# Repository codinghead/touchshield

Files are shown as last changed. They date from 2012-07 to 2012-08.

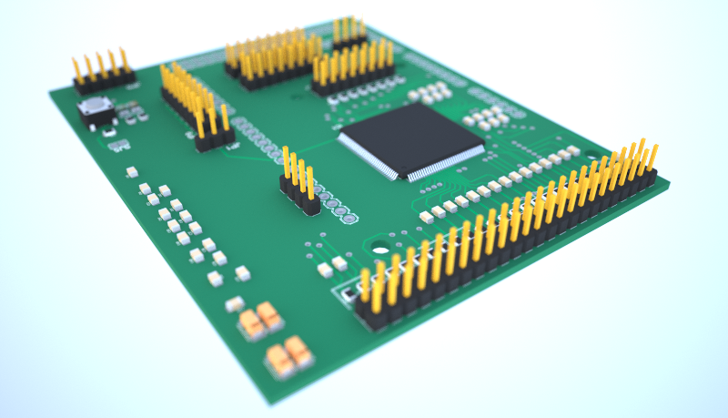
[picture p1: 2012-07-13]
images/QTouchShieldRender.png

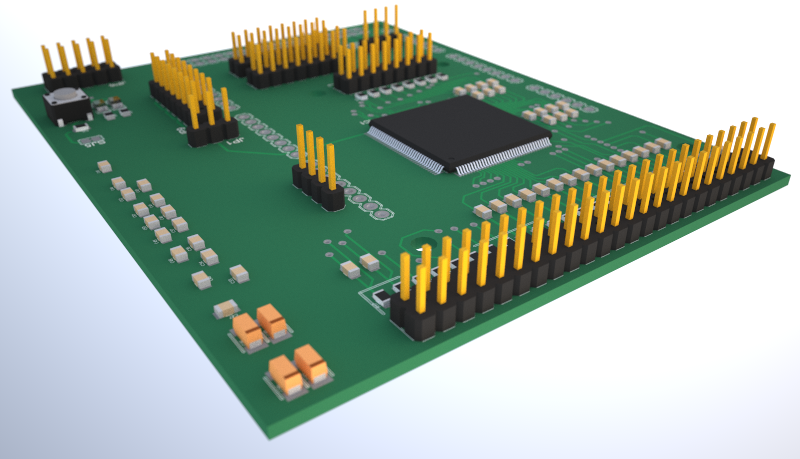
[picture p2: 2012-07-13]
images/QTouchShieldRender3.png

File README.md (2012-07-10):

QTouchShield for Arduino
========================

Introduction to the project
---------------------------

The QTouchShield for Arduino project aims to design a hardware platform for the Arduino MEGA that supports up to 32 configurable capacitive touch inputs.

The inputs can be configured as:

* Buttons
* Sliders
* Wheels
* Proximity sensors

Additionally the project includes the necessary firmware required by the shield's microcontroller to enable this functionality.

Key Capabilties
---------------
* Support up to 32 capacitive touch inputs supporting:
	* up to 8 sliders/wheels
	* up to 32 buttons
	* up to 32 proximity sensors
* Configuration via SPI or UART (RX/TX) interfaces
* Arduino library to simplify integration into sketches

Licensing
---------

The hardware is licensed under the Creative Commons ShareAlike license:

> This work is licensed under the Creative Commons Attribution-ShareAlike 3.0 Unported License.
> To view a copy of this license, visit [http://creativecommons.org/licenses/by-sa/3.0/] (http://creativecommons.org/licenses/by-sa/3.0/) or send
> a letter to:
> Creative Commons, 444 Castro Street, Suite 900, Mountain View, California, 94041, USA.

The software for the project is yet to be developed.

Project Page
------------

For all current information, visit the project page at [codinghead.github.com/touchshield] (http://codinghead.github.com/touchshield/).

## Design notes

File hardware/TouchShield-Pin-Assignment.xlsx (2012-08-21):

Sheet: Pin Assignment
AT32UC3C0512 |  |  | QTouchShield |  |  | Arduino MEGA 2560
LQFP144 Pin | PIN | STK600 | Assignment | Group | Description | Group | PIN | Function | Notes/Comments
1 | PA00 | PA0, TCK | TCK | JTAG | JTAG programming and debug i/f for AT32UC3C
2 | PA01 | PA1, TDI | TDI | JTAG | JTAG programming and debug i/f for AT32UC3C
3 | PA02 | PA2, TDO | TDO | JTAG | JTAG programming and debug i/f for AT32UC3C
4 | PA03 | PA3, TMS | TMS | JTAG | JTAG programming and debug i/f for AT32UC3C
5 | VDDIO1 | --- | 5.0V | SUPPLY | Power supply connection | POWER | 5V | 5V
6 | GNDIO1 | --- | 0.0V | SUPPLY | Power supply connection | POWER | GND | GND
7 | PB04 | PE4 | SNS04 | QT-SENSE | QTouch sense connection |  |  |  | Connect via X.XnF capacitor to SNSK04
8 | PB05 | PE5 | SNS05 | QT-SENSE | QTouch sense connection |  |  |  | Connect via X.XnF capacitor to SNSK05
9 | PB06 | PE6 | SNS06 | QT-SENSE | QTouch sense connection |  |  |  | Connect via X.XnF capacitor to SNSK06
10 | PB07 | PE7 | SNS07 | QT-SENSE | QTouch sense connection |  |  |  | Connect via X.XnF capacitor to SNSK07
11 | PB08 | PF0 | SNS08 | QT-SENSE | QTouch sense connection |  |  |  | Connect via X.XnF capacitor to SNSK08
12 | PB09 | PF1 | SNS09 | QT-SENSE | QTouch sense connection |  |  |  | Connect via X.XnF capacitor to SNSK09
13 | PB10 | PF2 | SNS10 | QT-SENSE | QTouch sense connection |  |  |  | Connect via X.XnF capacitor to SNSK10
14 | PB11 | PF3 | SNS11 | QT-SENSE | QTouch sense connection |  |  |  | Connect via X.XnF capacitor to SNSK11
15 | PB12 | PF4 | SNS12 | QT-SENSE | QTouch sense connection |  |  |  | Connect via X.XnF capacitor to SNSK12
16 | PB13 | PF5 | SNS13 | QT-SENSE | QTouch sense connection |  |  |  | Connect via X.XnF capacitor to SNSK13
17 | PB14 | PF6 | SNS14 | QT-SENSE | QTouch sense connection |  |  |  | Connect via X.XnF capacitor to SNSK14
18 | PB15 | PF7 | SNS15 | QT-SENSE | QTouch sense connection |  |  |  | Connect via X.XnF capacitor to SNSK15
19 | PB16 | PG0 | SNS16 | QT-SENSE | QTouch sense connection |  |  |  | Connect via X.XnF capacitor to SNSK16
20 | PB17 | PG1 | SNS17 | QT-SENSE | QTouch sense connection |  |  |  | Connect via X.XnF capacitor to SNSK17
21 | PA04 | PA4 | DETECT | QT-DETECT-GENERAL | At least one sensor is in detect - visual output |  |  |  | LED output to blink when a touch is detected on any of the inputs
22 | PA05 | PA5 | DATA_TRANSFER | SHIELD-DATA-TRANSFER | Data is being transferred on data link - visual output |  |  |  | LED output to blink when data is being shared with the Arduino
23 | PA06 | PA6 | DETECT-SENSOR00 | SHIELD-DETECT-OUTPUT | Digital output for detection on sensor 00
24 | PA07 | PA7 | DETECT-SENSOR01 | SHIELD-DETECT-OUTPUT | Digital output for detection on sensor 01
25 | PA08 | PB0 | DETECT-SENSOR02 | SHIELD-DETECT-OUTPUT | Digital output for detection on sensor 02
26 | PA09 | PB1 | DETECT-SENSOR03 | SHIELD-DETECT-OUTPUT | Digital output for detection on sensor 03
27 | PA10 | PB2 | DETECT-SENSOR04 | SHIELD-DETECT-OUTPUT | Digital output for detection on sensor 04
28 | PA11 | PB3, AREF1 | DETECT-SENSOR05 | SHIELD-DETECT-OUTPUT | Digital output for detection on sensor 05
29 | PA12 | PB4 | DETECT-SENSOR06 | SHIELD-DETECT-OUTPUT | Digital output for detection on sensor 06
30 | PA13 | PB5 | DETECT-SENSOR07 | SHIELD-DETECT-OUTPUT | Digital output for detection on sensor 07
31 | PA14 | PB6 | DETECT-SENSOR08 | SHIELD-DETECT-OUTPUT | Digital output for detection on sensor 08
32 | PA15 | PB7 | DETECT-SENSOR09 | SHIELD-DETECT-OUTPUT | Digital output for detection on sensor 09
33 | PA16 | PC0, AREF0 | DETECT-SENSOR10 | SHIELD-DETECT-OUTPUT | Digital output for detection on sensor 10
34 | ADCVREFP | --- | NC | NO_FUNCTION |  |  |  |  | Connect to ADCREFN via parallel capacitors of 33nF and 100nF
35 | ADCVREFN | --- | NC | NO_FUNCTION |  |  |  |  | Connect to ADCREFP via parallel capacitors of 33nF and 100nF
36 | PA19 | PC3 | DETECT-SENSOR11 | SHIELD-DETECT-OUTPUT | Digital output for detection on sensor 11
37 | GNDANA | --- | 0.0V | SUPPLY | Power supply connection | POWER | GND | GND | Connect via decoupling capacitors to UC3C to VDDANA
38 | VDDANA | VTG | 5.0V | SUPPLY | Power supply connection | POWER | 5V | 5V | Connect via inductor to 5V on Arduino
39 | PA20 | PC4 | DETECT-SENSOR12 | SHIELD-DETECT-OUTPUT | Digital output for detection on sensor 12
40 | PA21 | PC5 | DETECT-SENSOR13 | SHIELD-DETECT-OUTPUT | Digital output for detection on sensor 13
41 | PA22 | PC6 | DETECT-SENSOR14 | SHIELD-DETECT-OUTPUT | Digital output for detection on sensor 14
42 | PA23 | PC7 | DETECT-SENSOR15 | SHIELD-DETECT-OUTPUT | Digital output for detection on sensor 15
43 | PA24 | PD0 | DETECT-SENSOR16 | SHIELD-DETECT-OUTPUT | Digital output for detection on sensor 16
44 | PA25 | PD1 | DETECT-SENSOR17 | SHIELD-DETECT-OUTPUT | Digital output for detection on sensor 17
45 | PA26 | PD2 | DETECT-SENSOR18 | SHIELD-DETECT-OUTPUT | Digital output for detection on sensor 18
46 | PA27 | PD3 | DETECT-SENSOR19 | SHIELD-DETECT-OUTPUT | Digital output for detection on sensor 19
47 | PA28 | PD4 | DETECT-SENSOR20 | SHIELD-DETECT-OUTPUT | Digital output for detection on sensor 20
48 | PA29 | PD5 | DETECT-SENSOR21 | SHIELD-DETECT-OUTPUT | Digital output for detection on sensor 21
49 | VBUS | VBUST | 0.0V | SUPPLY |  | POWER | GND | GND | ??? Connect this unused pin to ground ???
50 | DM | DN | NC | NO_FUNCTION |  |  |  |  | ??? Perhaps use for USB firmware upgrade ???
51 | DP | DP | NC | NO_FUNCTION |  |  |  |  | ??? Perhaps use for USB firmware upgrade ???
52 | GNDPLL | --- | 0.0V | SUPPLY |  | POWER | GND | GND
53 | VDDIN_5 | --- | 5.0V | SUPPLY |  | POWER | 5V | 5V
54 | VDDIN_33 | --- | Regulator Decoupling | SUPPLY | Power supply decoupling | POWER | GND | GND | Connect via decoupling capacitors to GND
55 | VDDCORE | 0 | Regulator Decoupling | SUPPLY | Power supply decoupling | POWER | GND | GND | Connect via decoupling capacitors to GND
56 | GNDCORE | --- | 0.0V | SUPPLY |  | POWER | GND | GND
57 | PB18 | PG2 | SNS18 | QT-SENSE | QTouch sense connection |  |  |  | Connect via X.XnF capacitor to SNSK18
58 | PB19 | PG3 | SNS19 | QT-SENSE | QTouch sense connection |  |  |  | Connect via X.XnF capacitor to SNSK19
59 | PB20 | PG4 | SNS20 | QT-SENSE | QTouch sense connection |  |  |  | Connect via X.XnF capacitor to SNSK20
60 | PB21 | PG5 | SNS21 | QT-SENSE | QTouch sense connection |  |  |  | Connect via X.XnF capacitor to SNSK21
61 | PB22 | PG6 | SNS22 | QT-SENSE | QTouch sense connection |  |  |  | Connect via X.XnF capacitor to SNSK22
62 | PB23 | PG7 | SNS23 | QT-SENSE | QTouch sense connection |  |  |  | Connect via X.XnF capacitor to SNSK23
63 | PB24 | PH0 | SNS24 | QT-SENSE | QTouch sense connection |  |  |  | Connect via X.XnF capacitor to SNSK24
64 | PB25 | PH1 | SNS25 | QT-SENSE | QTouch sense connection |  |  |  | Connect via X.XnF capacitor to SNSK25
65 | PB26 | PH2 | SNS26 | QT-SENSE | QTouch sense connection |  |  |  | Connect via X.XnF capacitor to SNSK26
66 | PB27 | PH3 | SNS27 | QT-SENSE | QTouch sense connection |  |  |  | Connect via X.XnF capacitor to SNSK27
67 | PB28 | PH4 | SNS28 | QT-SENSE | QTouch sense connection |  |  |  | Connect via X.XnF capacitor to SNSK28
68 | PB29 | PH5 | SNS29 | QT-SENSE | QTouch sense connection |  |  |  | Connect via X.XnF capacitor to SNSK29
69 | PB30 | PH6, XTAL1 | SNS30 | QT-SENSE | QTouch sense connection |  |  |  | Connect via X.XnF capacitor to SNSK30
70 | PB31 | PH7, XTAL2 | SNS31 | QT-SENSE | QTouch sense connection |  |  |  | Connect via X.XnF capacitor to SNSK31
71 | PC00 | PJ0 | SNSK00 | QT-SENSE-KEY | QTouch key connection |  |  |  | Connect to X.XkOhn resistor -> header with local header pin for GND of sensor wiring
72 | PC01 | PJ1, UVCON | SNSK01 | QT-SENSE-KEY | QTouch key connection |  |  |  | Connect to X.XkOhn resistor -> header with local header pin for GND of sensor wiring
73 | PC02 | PJ2 | SNSK02 | QT-SENSE-KEY | QTouch key connection |  |  |  | Connect to X.XkOhn resistor -> header with local header pin for GND of sensor wiring
74 | PC03 | PJ3 | SNSK03 | QT-SENSE-KEY | QTouch key connection |  |  |  | Connect to X.XkOhn resistor -> header with local header pin for GND of sensor wiring
75 | VDDIO2 | --- | 5.0V | SUPPLY | Supply | POWER | 5V | 5V
76 | GNDIO2 | --- | 0.0V | SUPPLY | Supply | POWER | GND | GND
77 | PC04 | PJ4 | SNSK04 | QT-SENSE-KEY | QTouch key connection |  |  |  | Connect to X.XkOhn resistor -> header with local header pin for GND of sensor wiring
78 | PC05 | PJ5 | SNSK05 | QT-SENSE-KEY | QTouch key connection |  |  |  | Connect to X.XkOhn resistor -> header with local header pin for GND of sensor wiring
79 | PC06 | PJ6 | SNSK06 | QT-SENSE-KEY | QTouch key connection |  |  |  | Connect to X.XkOhn resistor -> header with local header pin for GND of sensor wiring
80 | PC07 | PJ7 | SNSK07 | QT-SENSE-KEY | QTouch key connection |  |  |  | Connect to X.XkOhn resistor -> header with local header pin for GND of sensor wiring
81 | PC08 | PK0 | SNSK08 | QT-SENSE-KEY | QTouch key connection |  |  |  | Connect to X.XkOhn resistor -> header with local header pin for GND of sensor wiring
82 | PC09 | PK1 | SNSK09 | QT-SENSE-KEY | QTouch key connection |  |  |  | Connect to X.XkOhn resistor -> header with local header pin for GND of sensor wiring
83 | PC10 | PK2 | SNSK10 | QT-SENSE-KEY | QTouch key connection |  |  |  | Connect to X.XkOhn resistor -> header with local header pin for GND of sensor wiring
84 | PC11 | PK3 | SNSK11 | QT-SENSE-KEY | QTouch key connection |  |  |  | Connect to X.XkOhn resistor -> header with local header pin for GND of sensor wiring
85 | PC12 | PK4 | SNSK12 | QT-SENSE-KEY | QTouch key connection |  |  |  | Connect to X.XkOhn resistor -> header with local header pin for GND of sensor wiring
86 | PC13 | PK5 | SNSK13 | QT-SENSE-KEY | QTouch key connection |  |  |  | Connect to X.XkOhn resistor -> header with local header pin for GND of sensor wiring
87 | PC14 | PK6 | SNSK14 | QT-SENSE-KEY | QTouch key connection |  |  |  | Connect to X.XkOhn resistor -> header with local header pin for GND of sensor wiring
88 | PC15 | PK7 | SNSK15 | QT-SENSE-KEY | QTouch key connection |  |  |  | Connect to X.XkOhn resistor -> header with local header pin for GND of sensor wiring
89 | PC16 | PL0 | SNSK16 | QT-SENSE-KEY | QTouch key connection |  |  |  | Connect to X.XkOhn resistor -> header with local header pin for GND of sensor wiring
90 | PC17 | PL1 | SNSK17 | QT-SENSE-KEY | QTouch key connection |  |  |  | Connect to X.XkOhn resistor -> header with local header pin for GND of sensor wiring
91 | PC18 | PL2 | SNSK18 | QT-SENSE-KEY | QTouch key connection |  |  |  | Connect to X.XkOhn resistor -> header with local header pin for GND of sensor wiring
92 | PC19 | PL3 | SNSK19 | QT-SENSE-KEY | QTouch key connection |  |  |  | Connect to X.XkOhn resistor -> header with local header pin for GND of sensor wiring
93 | PC20 | PL4 | SNSK20 | QT-SENSE-KEY | QTouch key connection |  |  |  | Connect to X.XkOhn resistor -> header with local header pin for GND of sensor wiring
94 | PC21 | PL5 | SNSK21 | QT-SENSE-KEY | QTouch key connection |  |  |  | Connect to X.XkOhn resistor -> header with local header pin for GND of sensor wiring
95 | PC22 | PL6 | SNSK22 | QT-SENSE-KEY | QTouch key connection |  |  |  | Connect to X.XkOhn resistor -> header with local header pin for GND of sensor wiring
96 | PC23 | PL7 | SNSK23 | QT-SENSE-KEY | QTouch key connection |  |  |  | Connect to X.XkOhn resistor -> header with local header pin for GND of sensor wiring
97 | PC24 | PM0 | SNSK24 | QT-SENSE-KEY | QTouch key connection |  |  |  | Connect to X.XkOhn resistor -> header with local header pin for GND of sensor wiring
98 | PC25 | PM1 | SNSK25 | QT-SENSE-KEY | QTouch key connection |  |  |  | Connect to X.XkOhn resistor -> header with local header pin for GND of sensor wiring
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

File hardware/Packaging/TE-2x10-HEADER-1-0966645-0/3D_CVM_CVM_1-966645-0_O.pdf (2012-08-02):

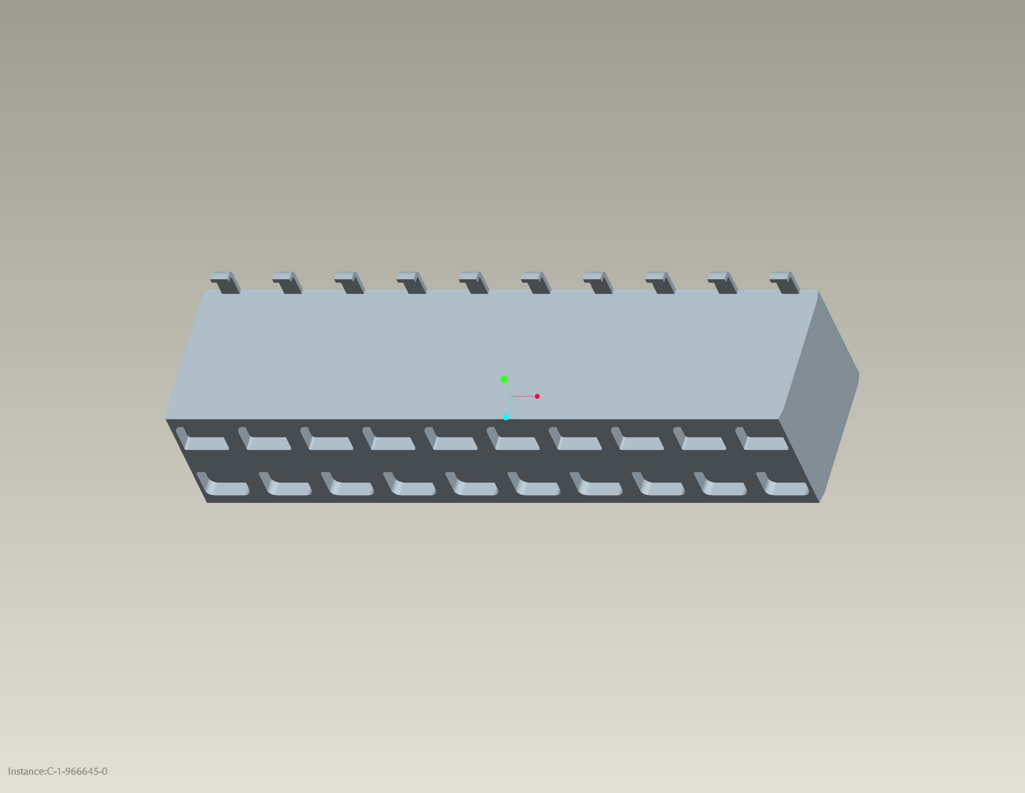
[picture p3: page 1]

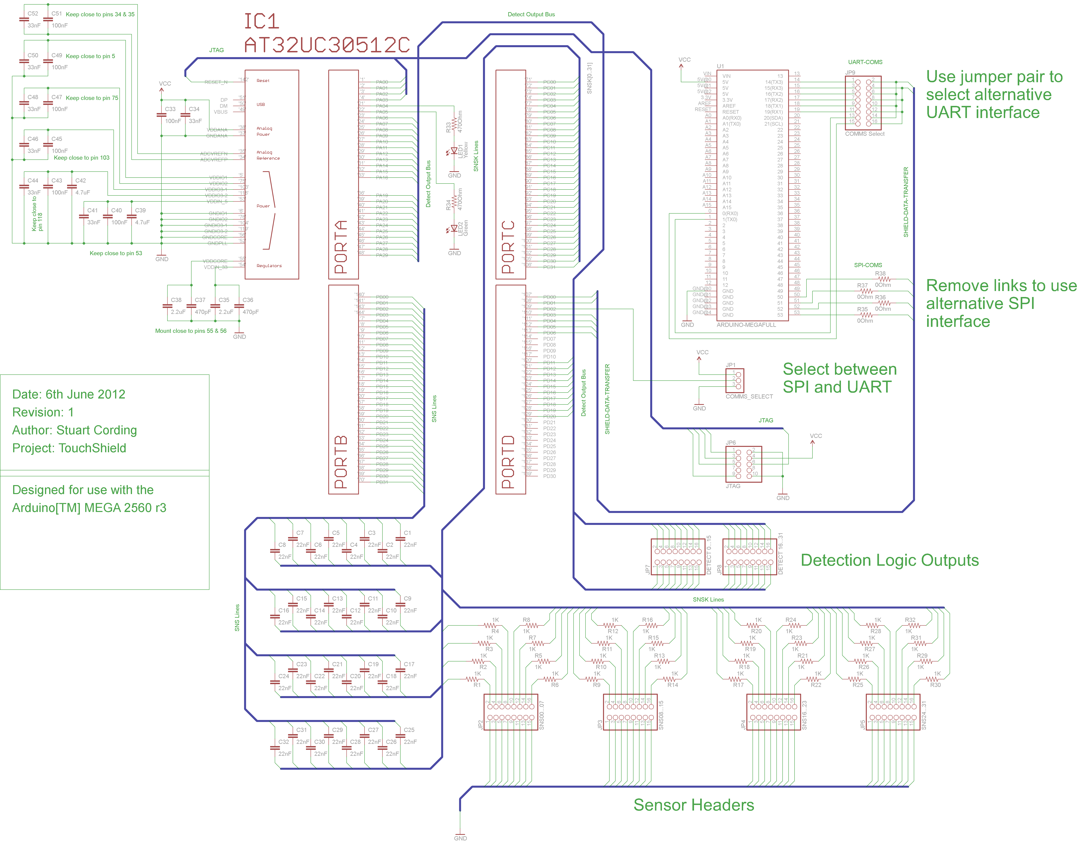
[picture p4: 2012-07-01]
hardware/QTouchShield/TouchShield-Rev1.png

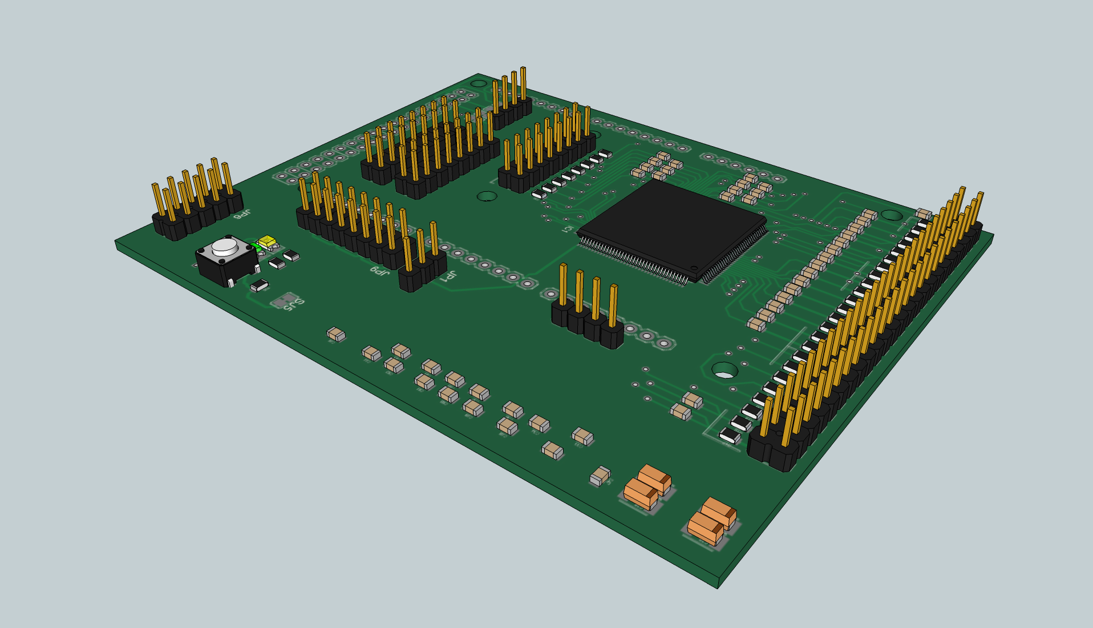
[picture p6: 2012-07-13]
images/QTouchShield.png

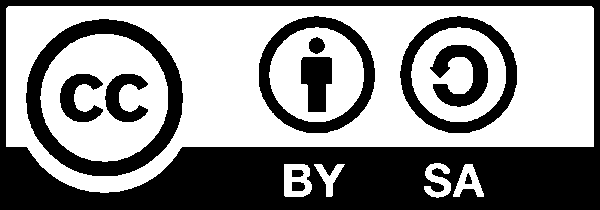
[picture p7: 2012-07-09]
images/by-sa-2-colours.bmp

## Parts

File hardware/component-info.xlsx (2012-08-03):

Component | Size | Type | Supplier | Series | Supplier# | Channel | Order# | Link
Socket Header | 2x10 | SMD | TE Connectivity |  | 1-966737-0 | Bürklin | 59 F 5693
Receptacle | 2x8 | SMD | FCI | Minitek | 20021321-00016C4LF | RS | 714-1230 | http://uk.rs-online.com/web/p/headers-pcb-receptacles/7141230/
Receptacle | 2x8 | SMD | FCI | Minitek | 20021321-00016C4LF | Farnell | 1865311 | http://uk.farnell.com/fci/20021321-00016c4lf/receptacle-vert-1-27mm-smt-16way/dp/1865311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
Receptacle | 2x8 | SMD | HARWIN |  | M20-7870842 |  |  | http://www.harwin.com/search/M20-7870842?ProductSearch=True

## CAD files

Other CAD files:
hardware/Packaging/HARWIN-2,54mm-dual-row-SMD-receptacle/M20.skp
hardware/QTouchShield/eagleUp/QTouchShield.skp

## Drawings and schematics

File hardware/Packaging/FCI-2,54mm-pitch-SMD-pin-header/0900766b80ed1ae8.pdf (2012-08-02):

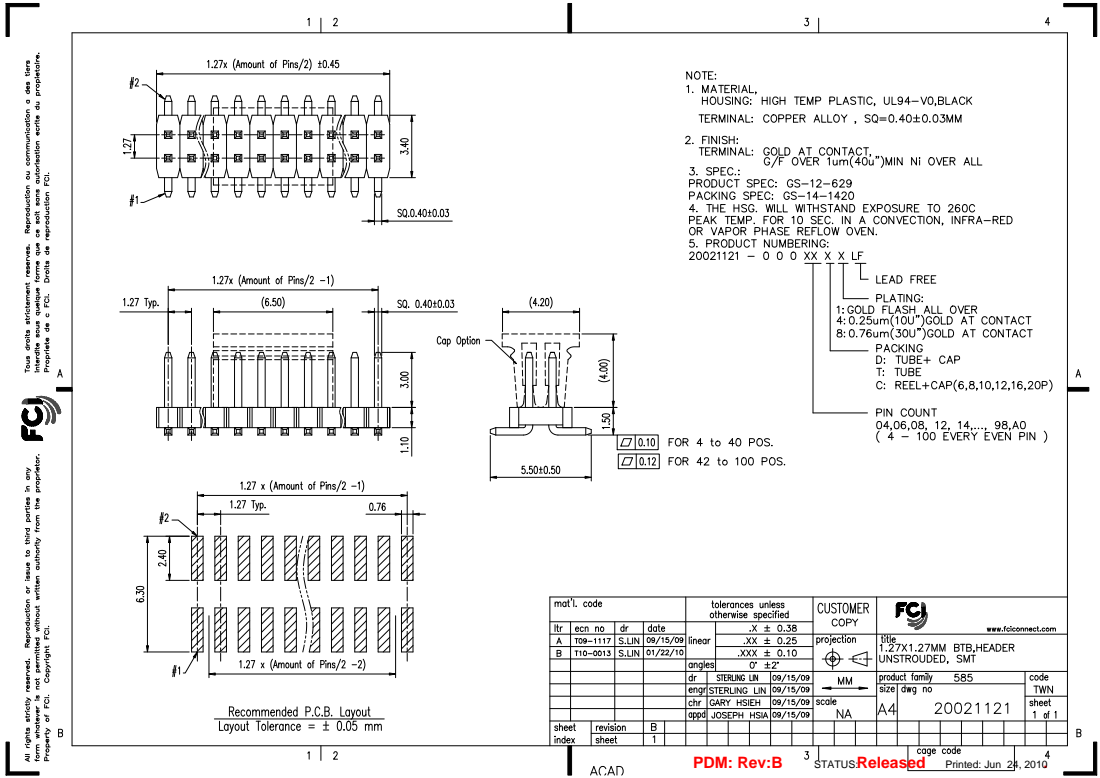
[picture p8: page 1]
PDM: Rev:B; Released; . STATUS:; Printed: Jun 24, 2010

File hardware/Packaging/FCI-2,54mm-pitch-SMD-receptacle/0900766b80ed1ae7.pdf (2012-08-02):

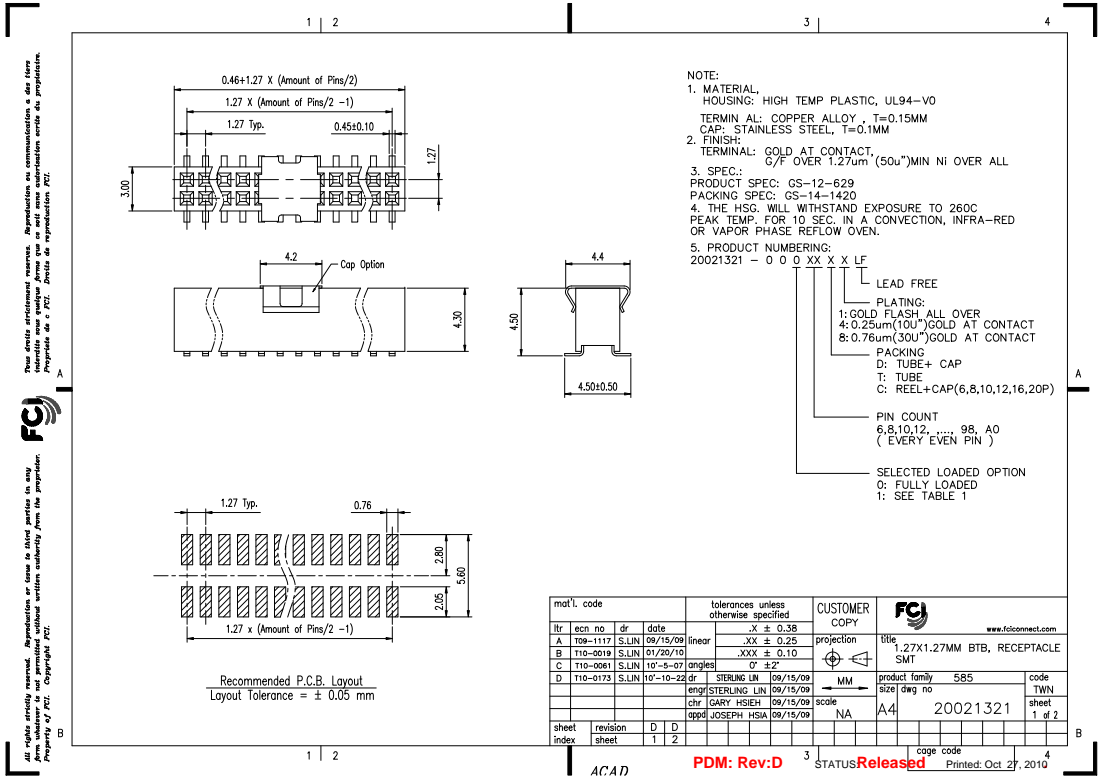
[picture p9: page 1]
PDM: Rev:D; Released; . STATUS:; Printed: Oct 27, 2010

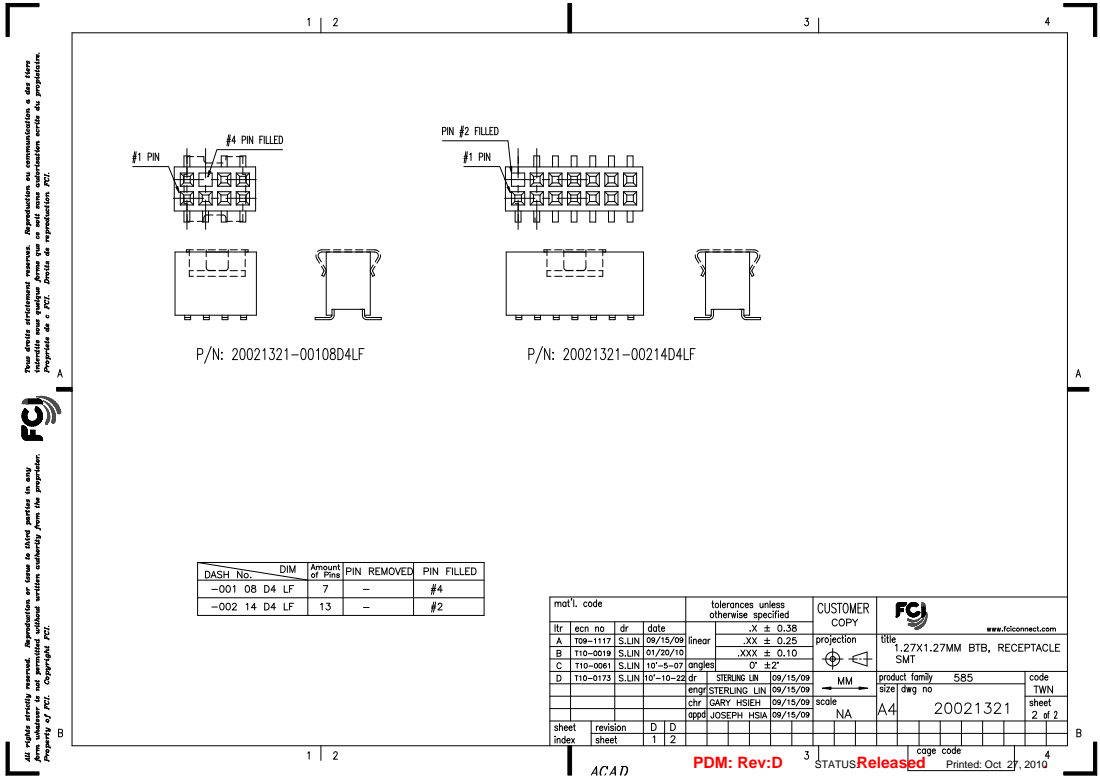
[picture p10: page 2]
PDM: Rev:D; Released; . STATUS:; Printed: Oct 27, 2010

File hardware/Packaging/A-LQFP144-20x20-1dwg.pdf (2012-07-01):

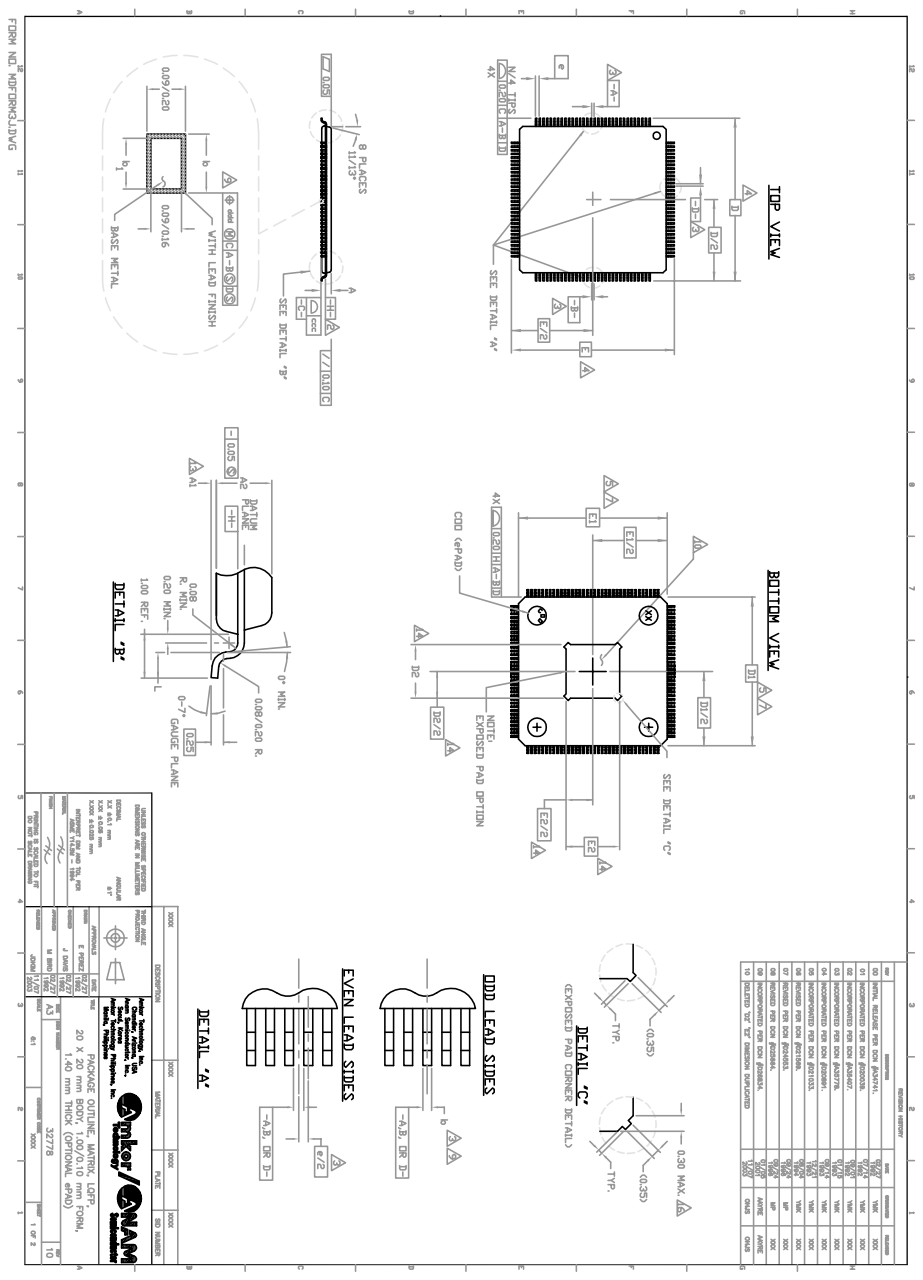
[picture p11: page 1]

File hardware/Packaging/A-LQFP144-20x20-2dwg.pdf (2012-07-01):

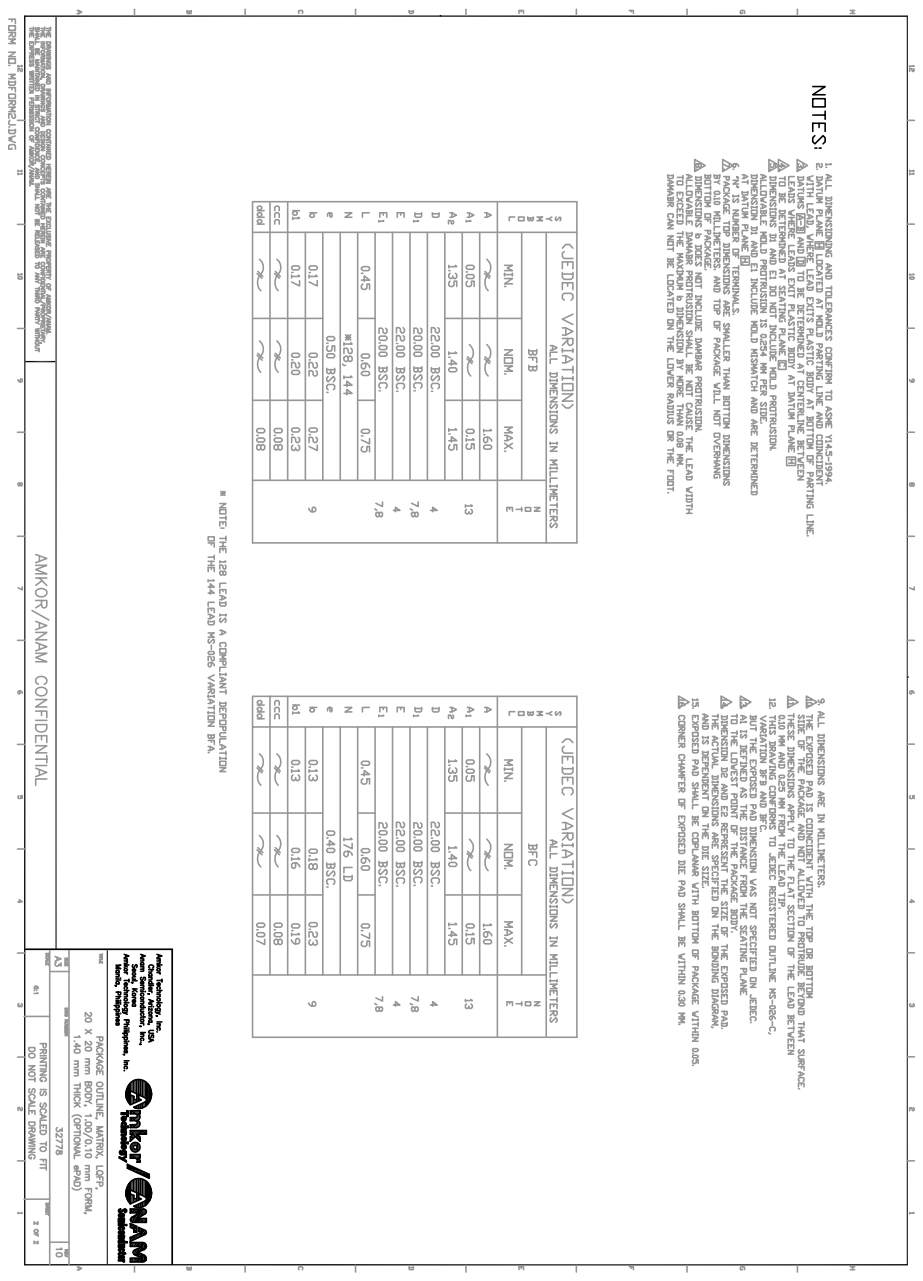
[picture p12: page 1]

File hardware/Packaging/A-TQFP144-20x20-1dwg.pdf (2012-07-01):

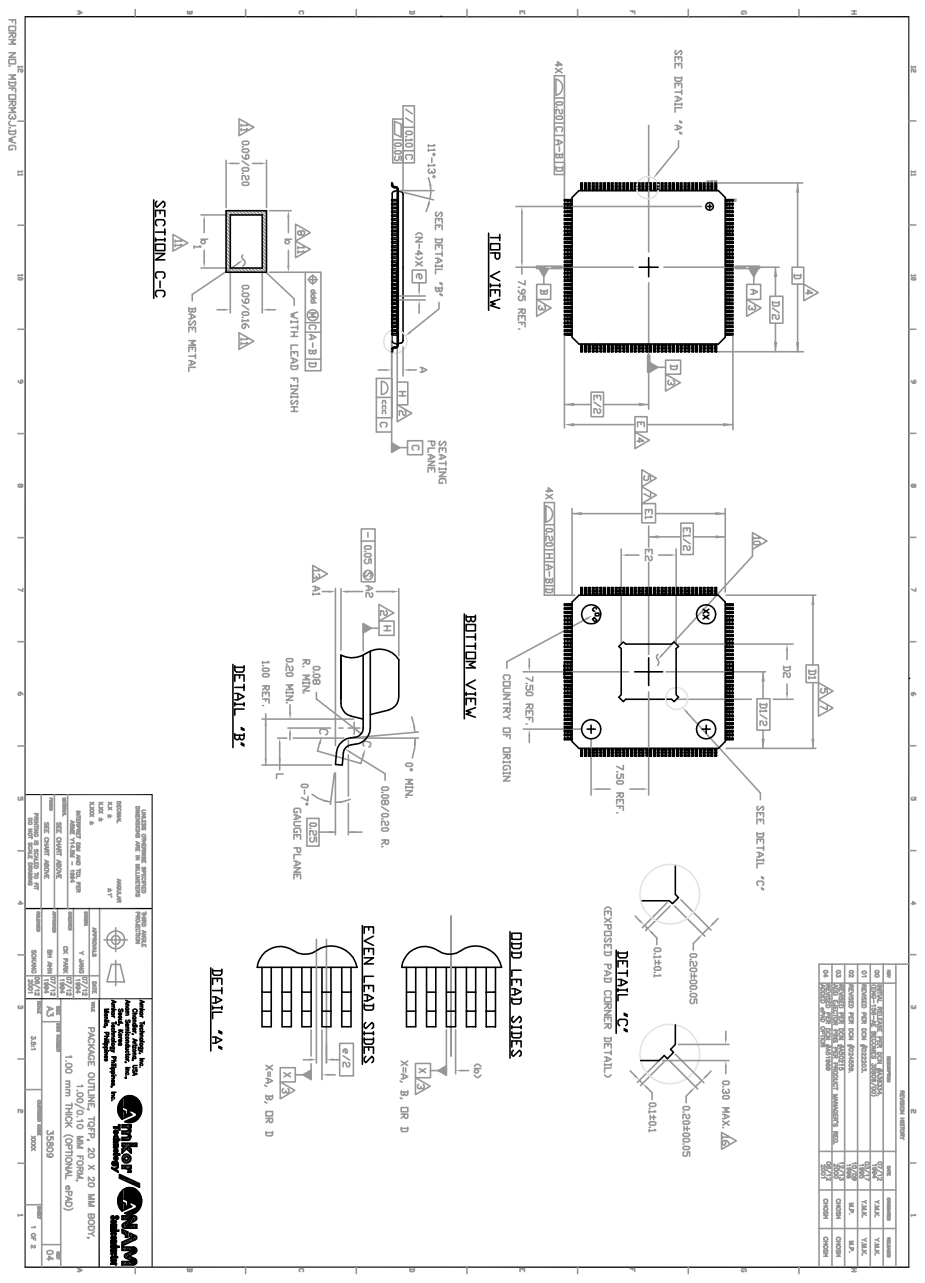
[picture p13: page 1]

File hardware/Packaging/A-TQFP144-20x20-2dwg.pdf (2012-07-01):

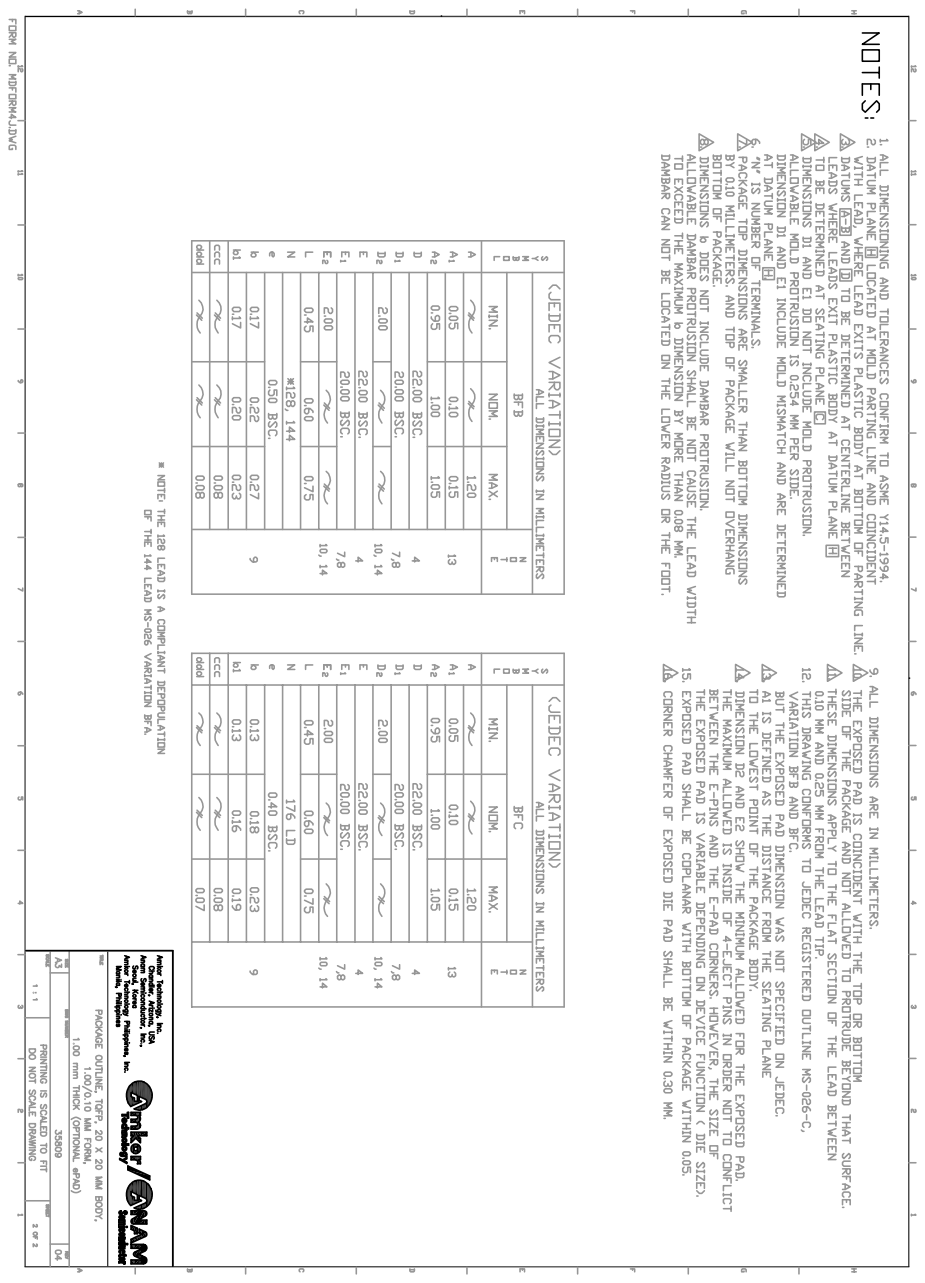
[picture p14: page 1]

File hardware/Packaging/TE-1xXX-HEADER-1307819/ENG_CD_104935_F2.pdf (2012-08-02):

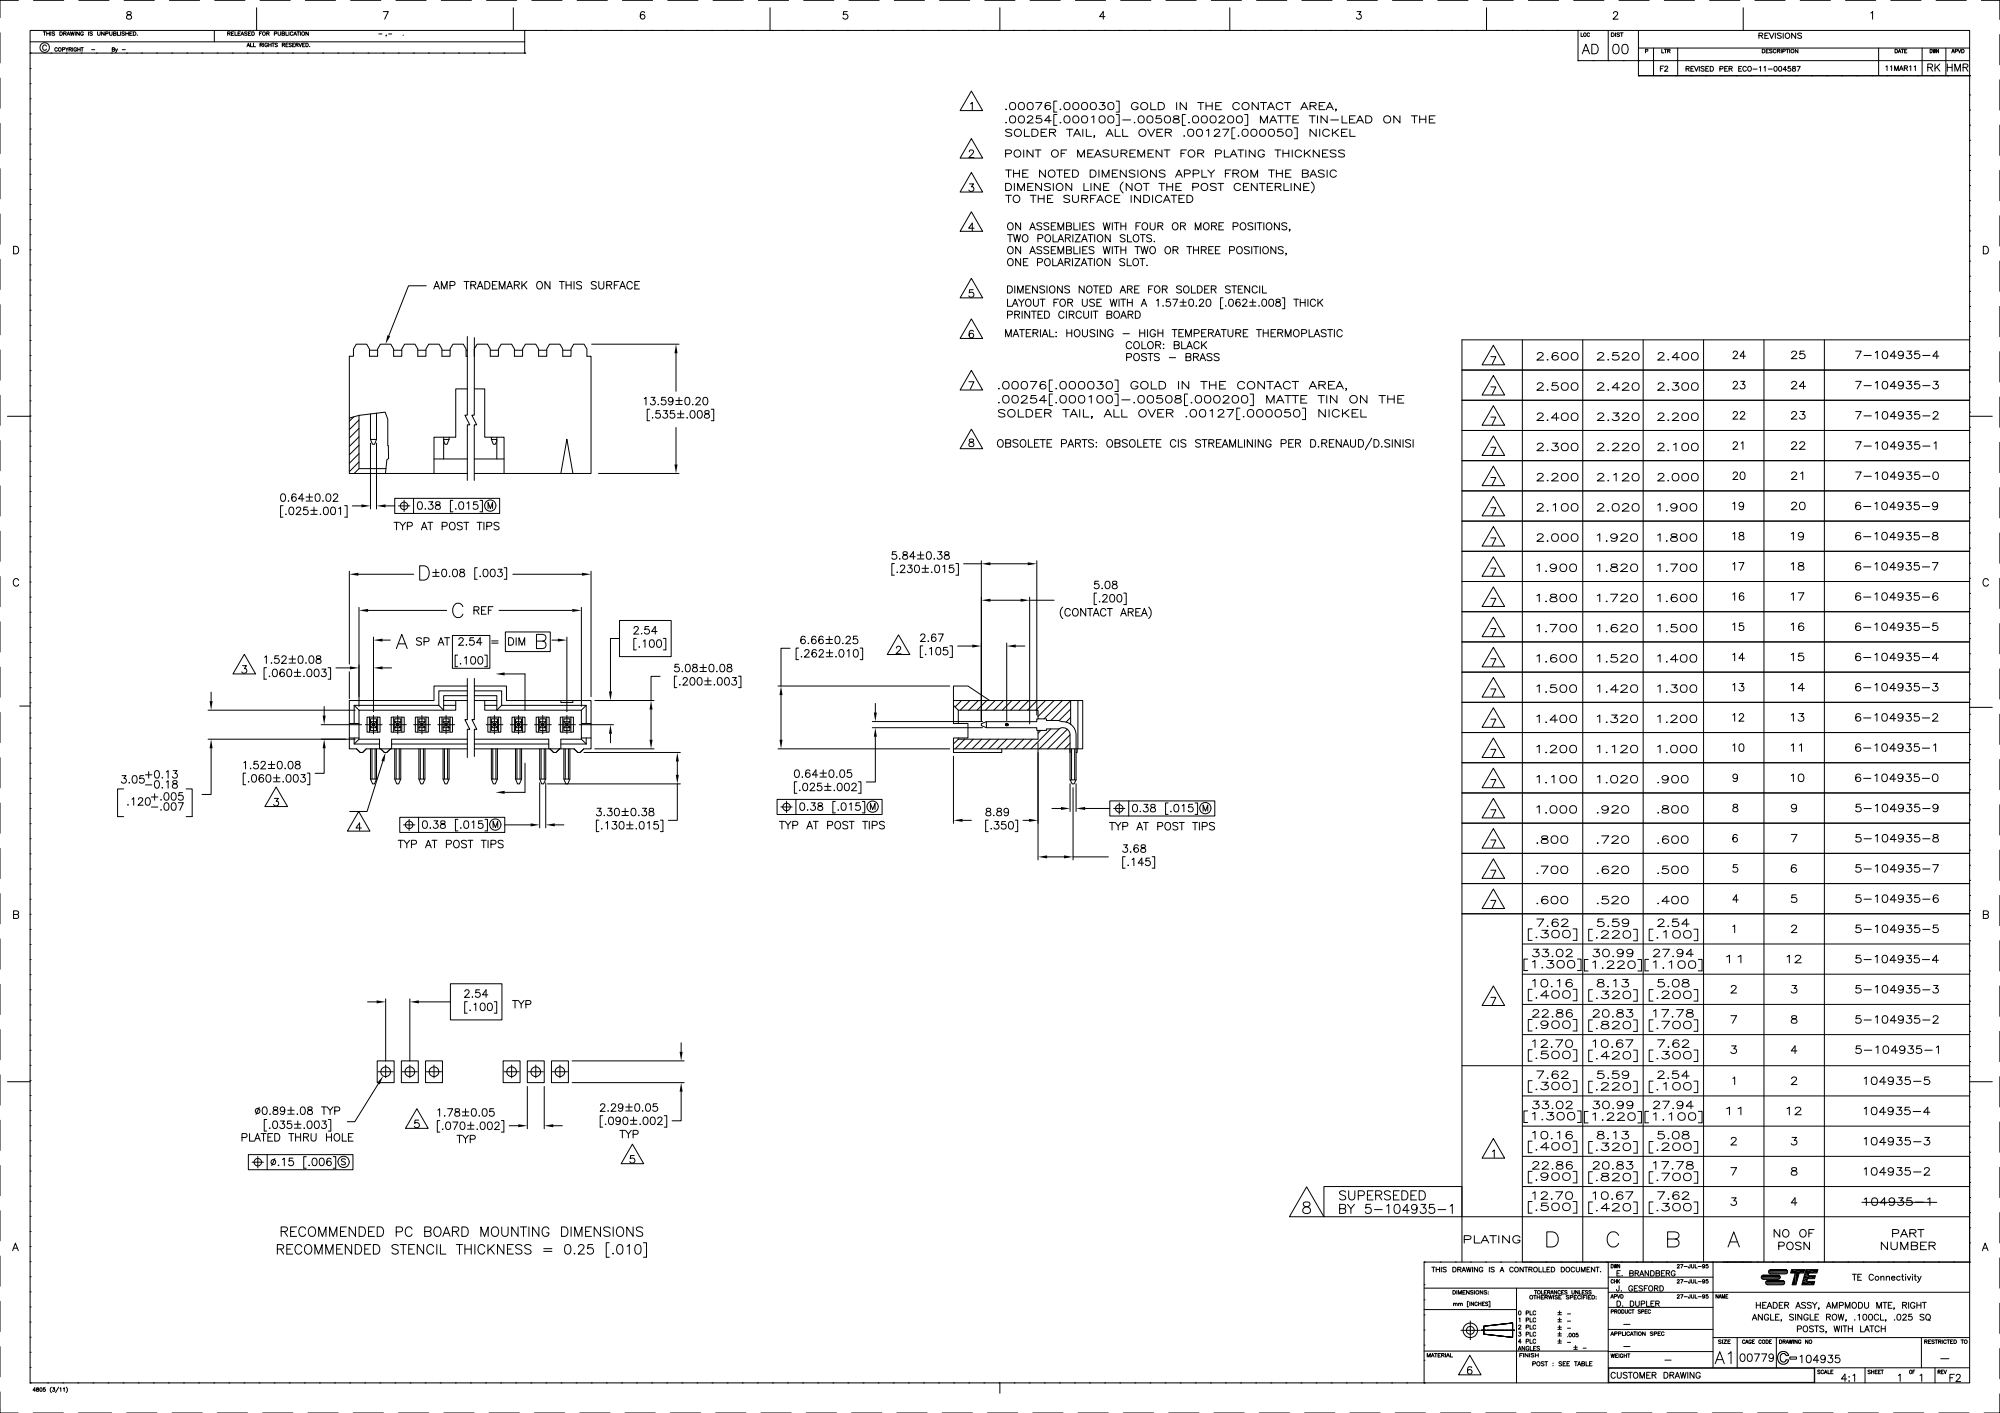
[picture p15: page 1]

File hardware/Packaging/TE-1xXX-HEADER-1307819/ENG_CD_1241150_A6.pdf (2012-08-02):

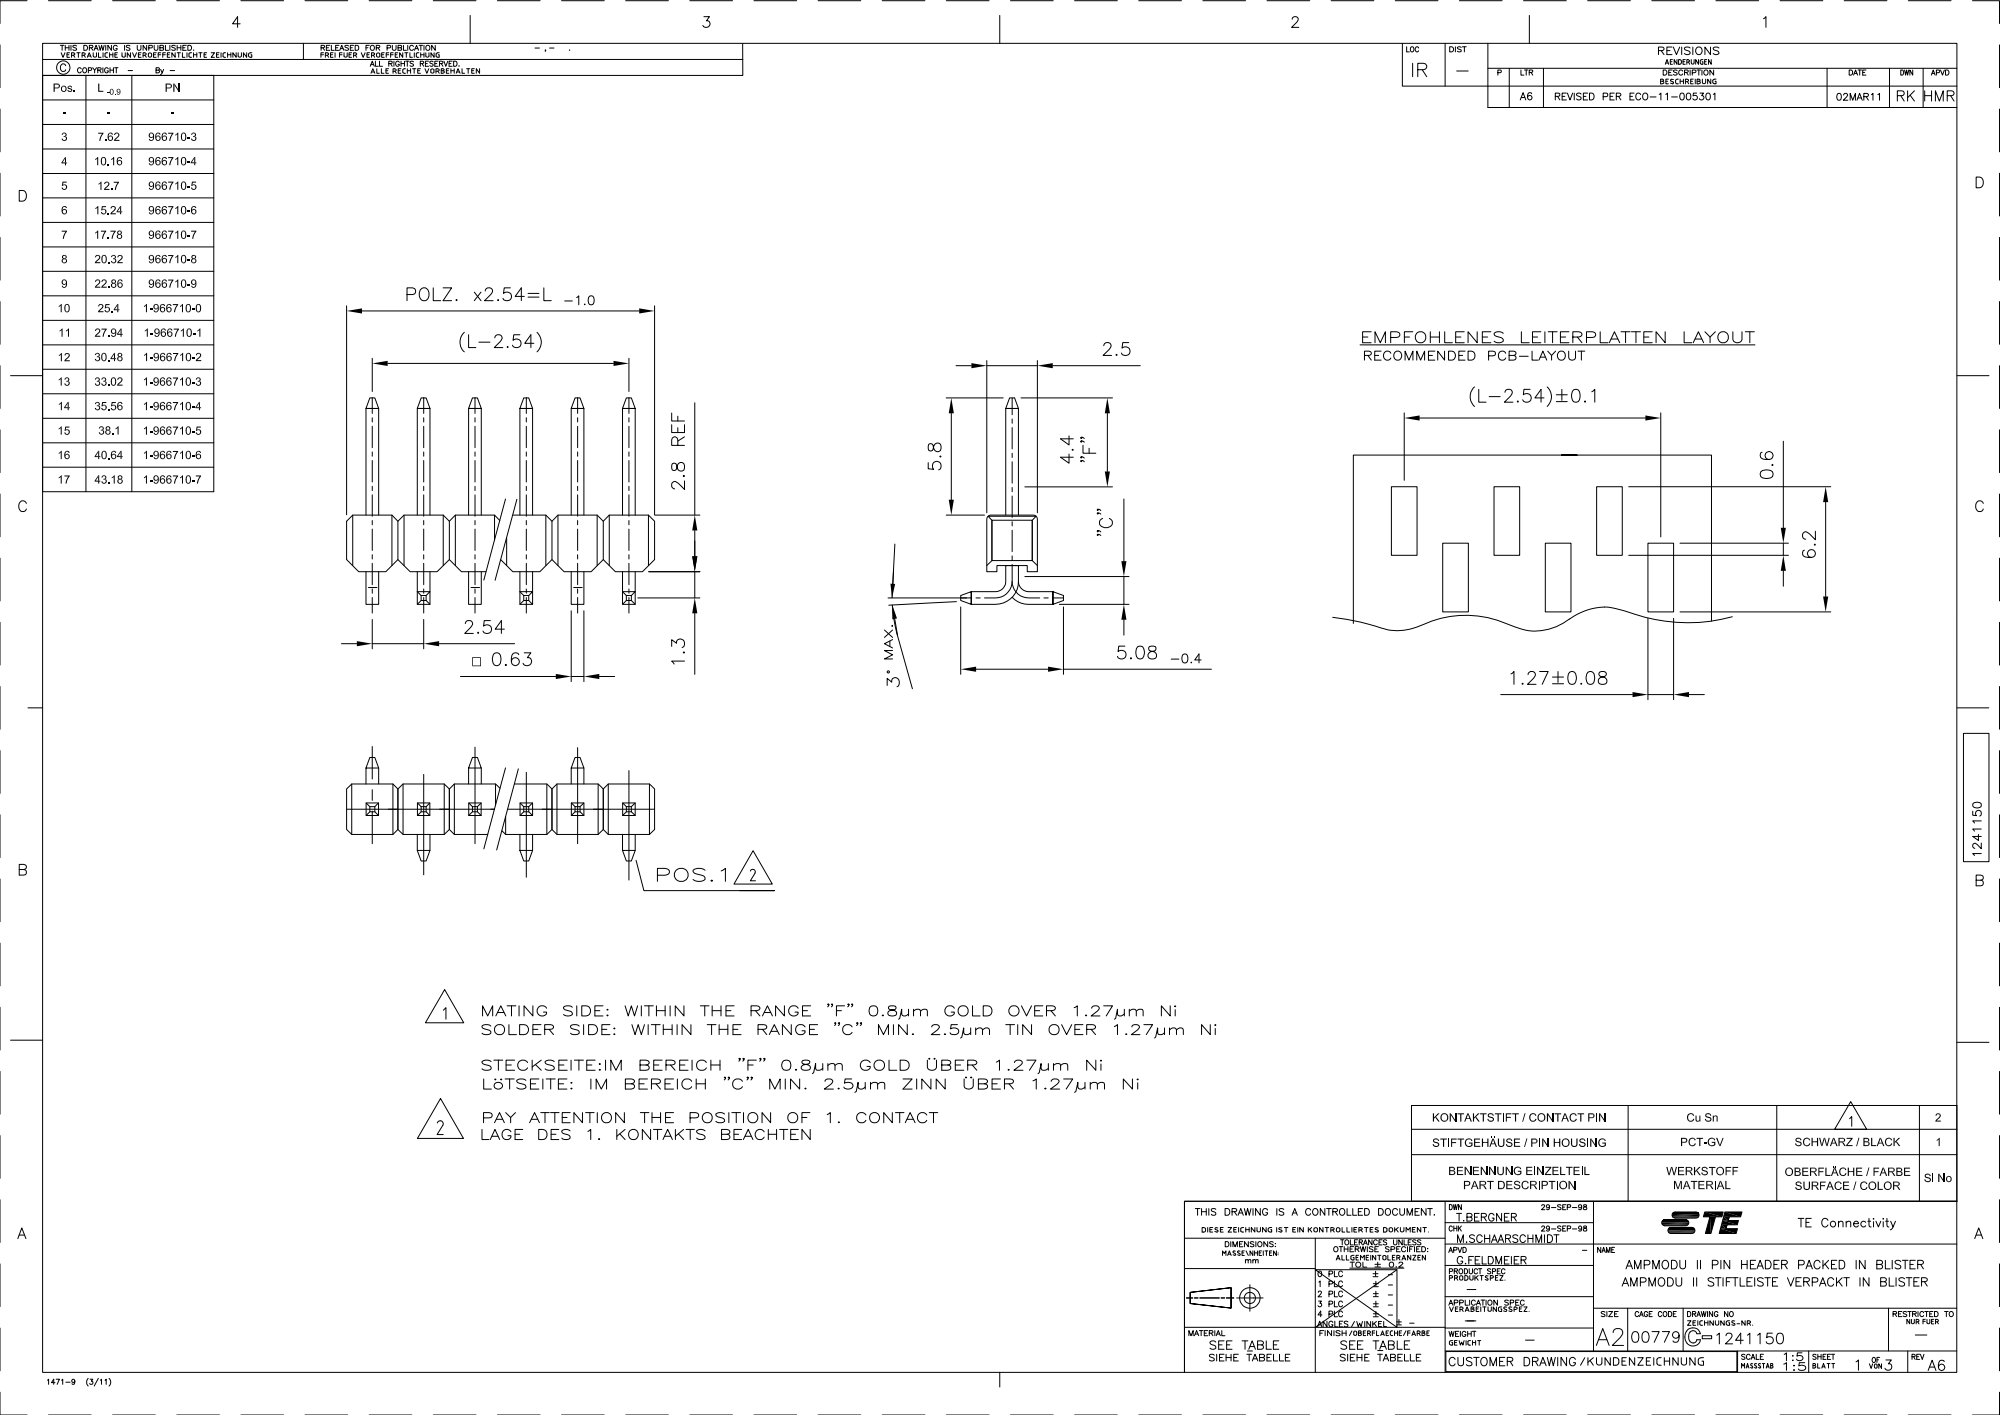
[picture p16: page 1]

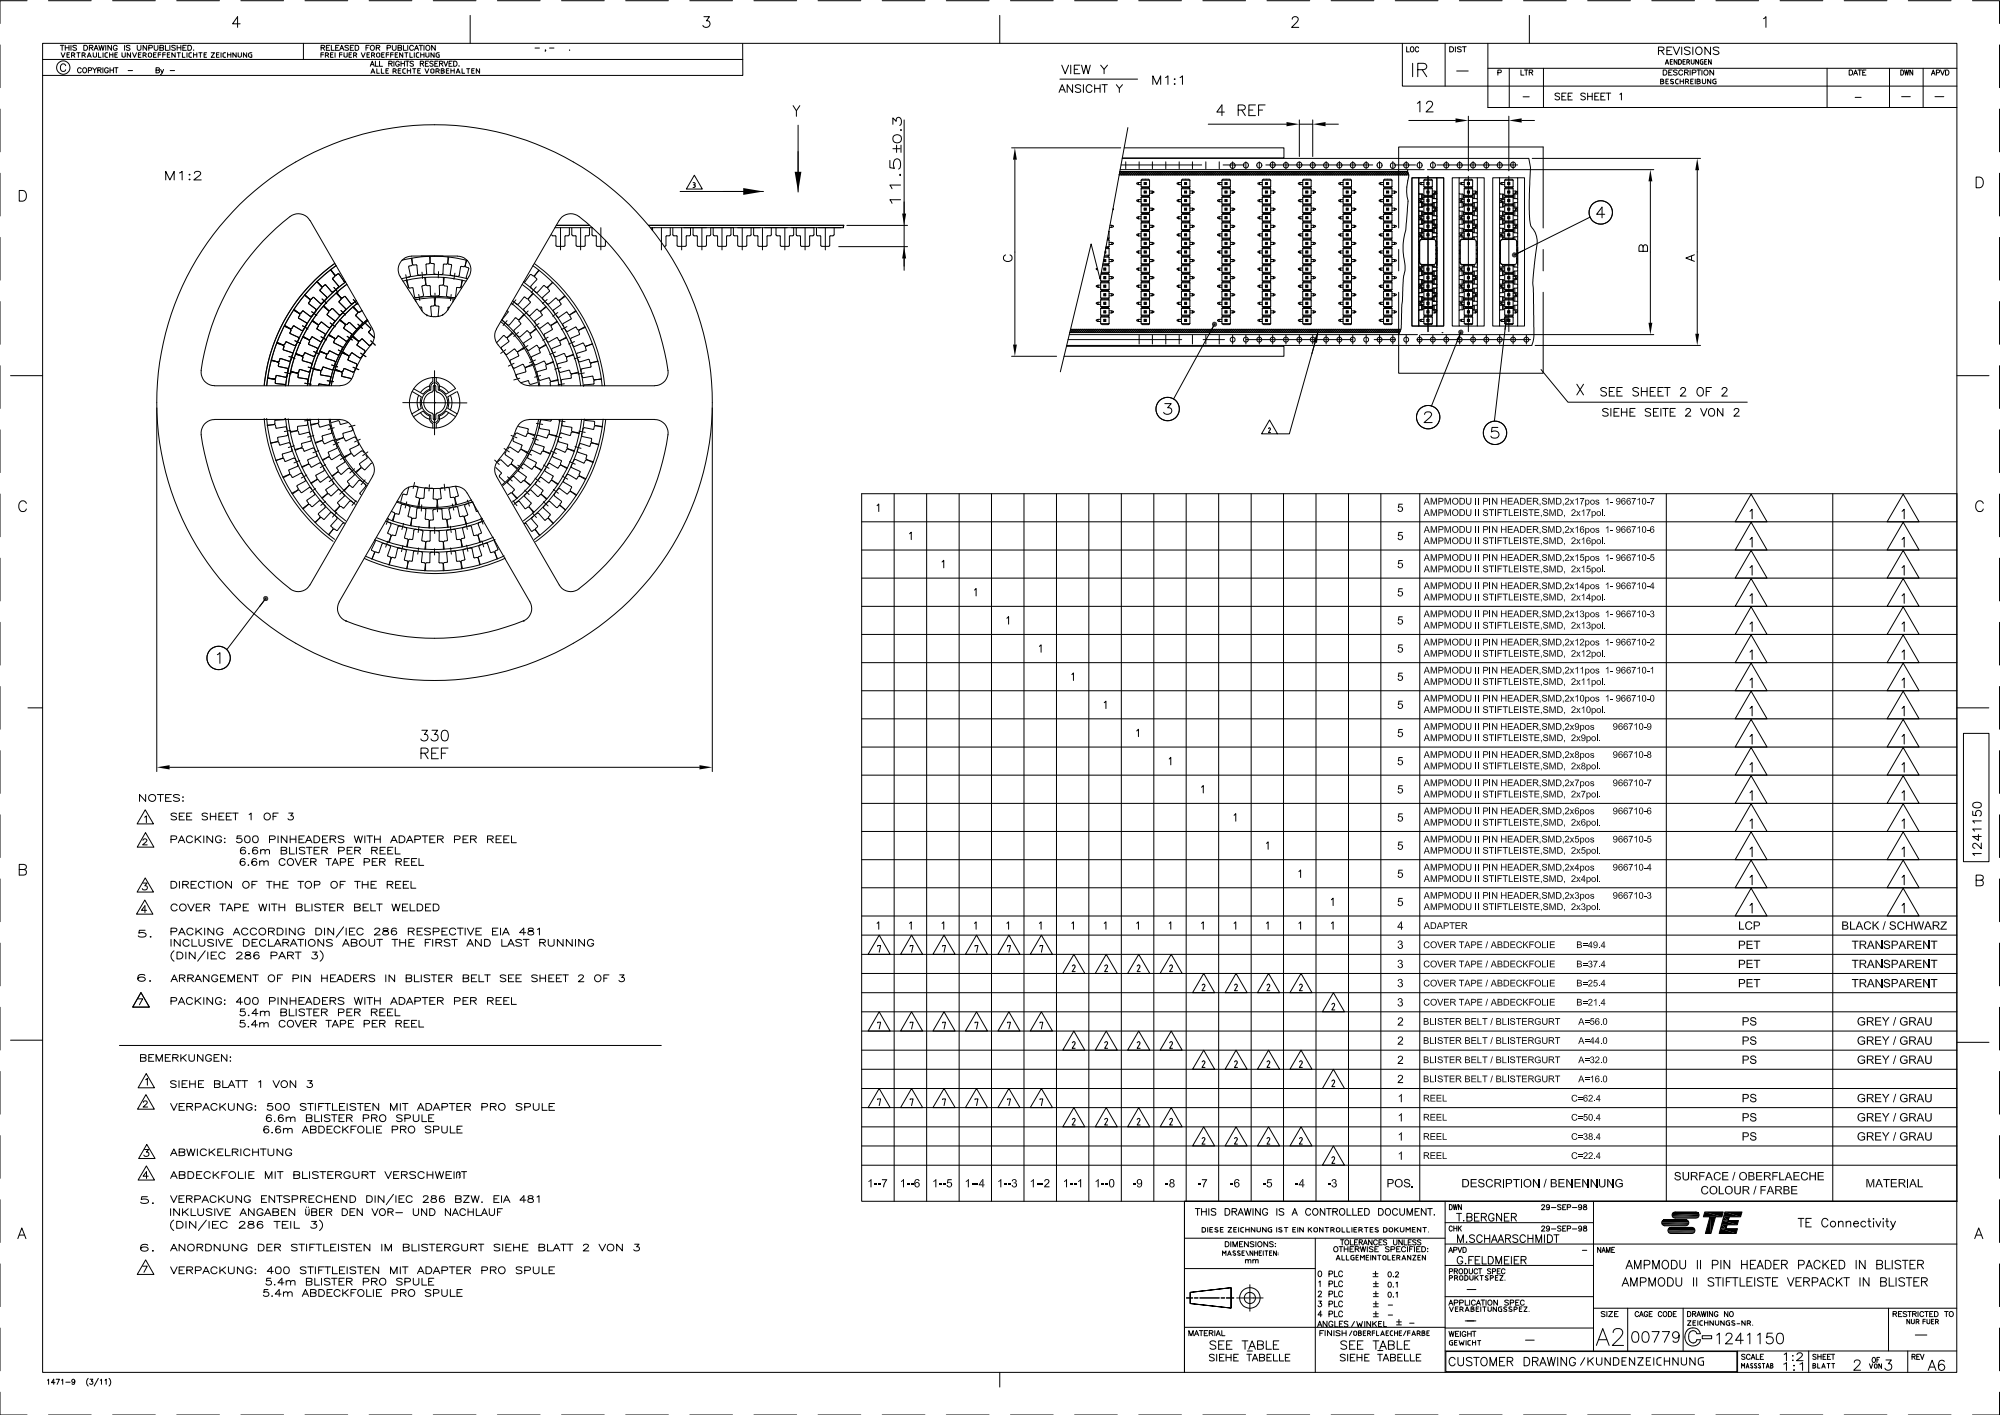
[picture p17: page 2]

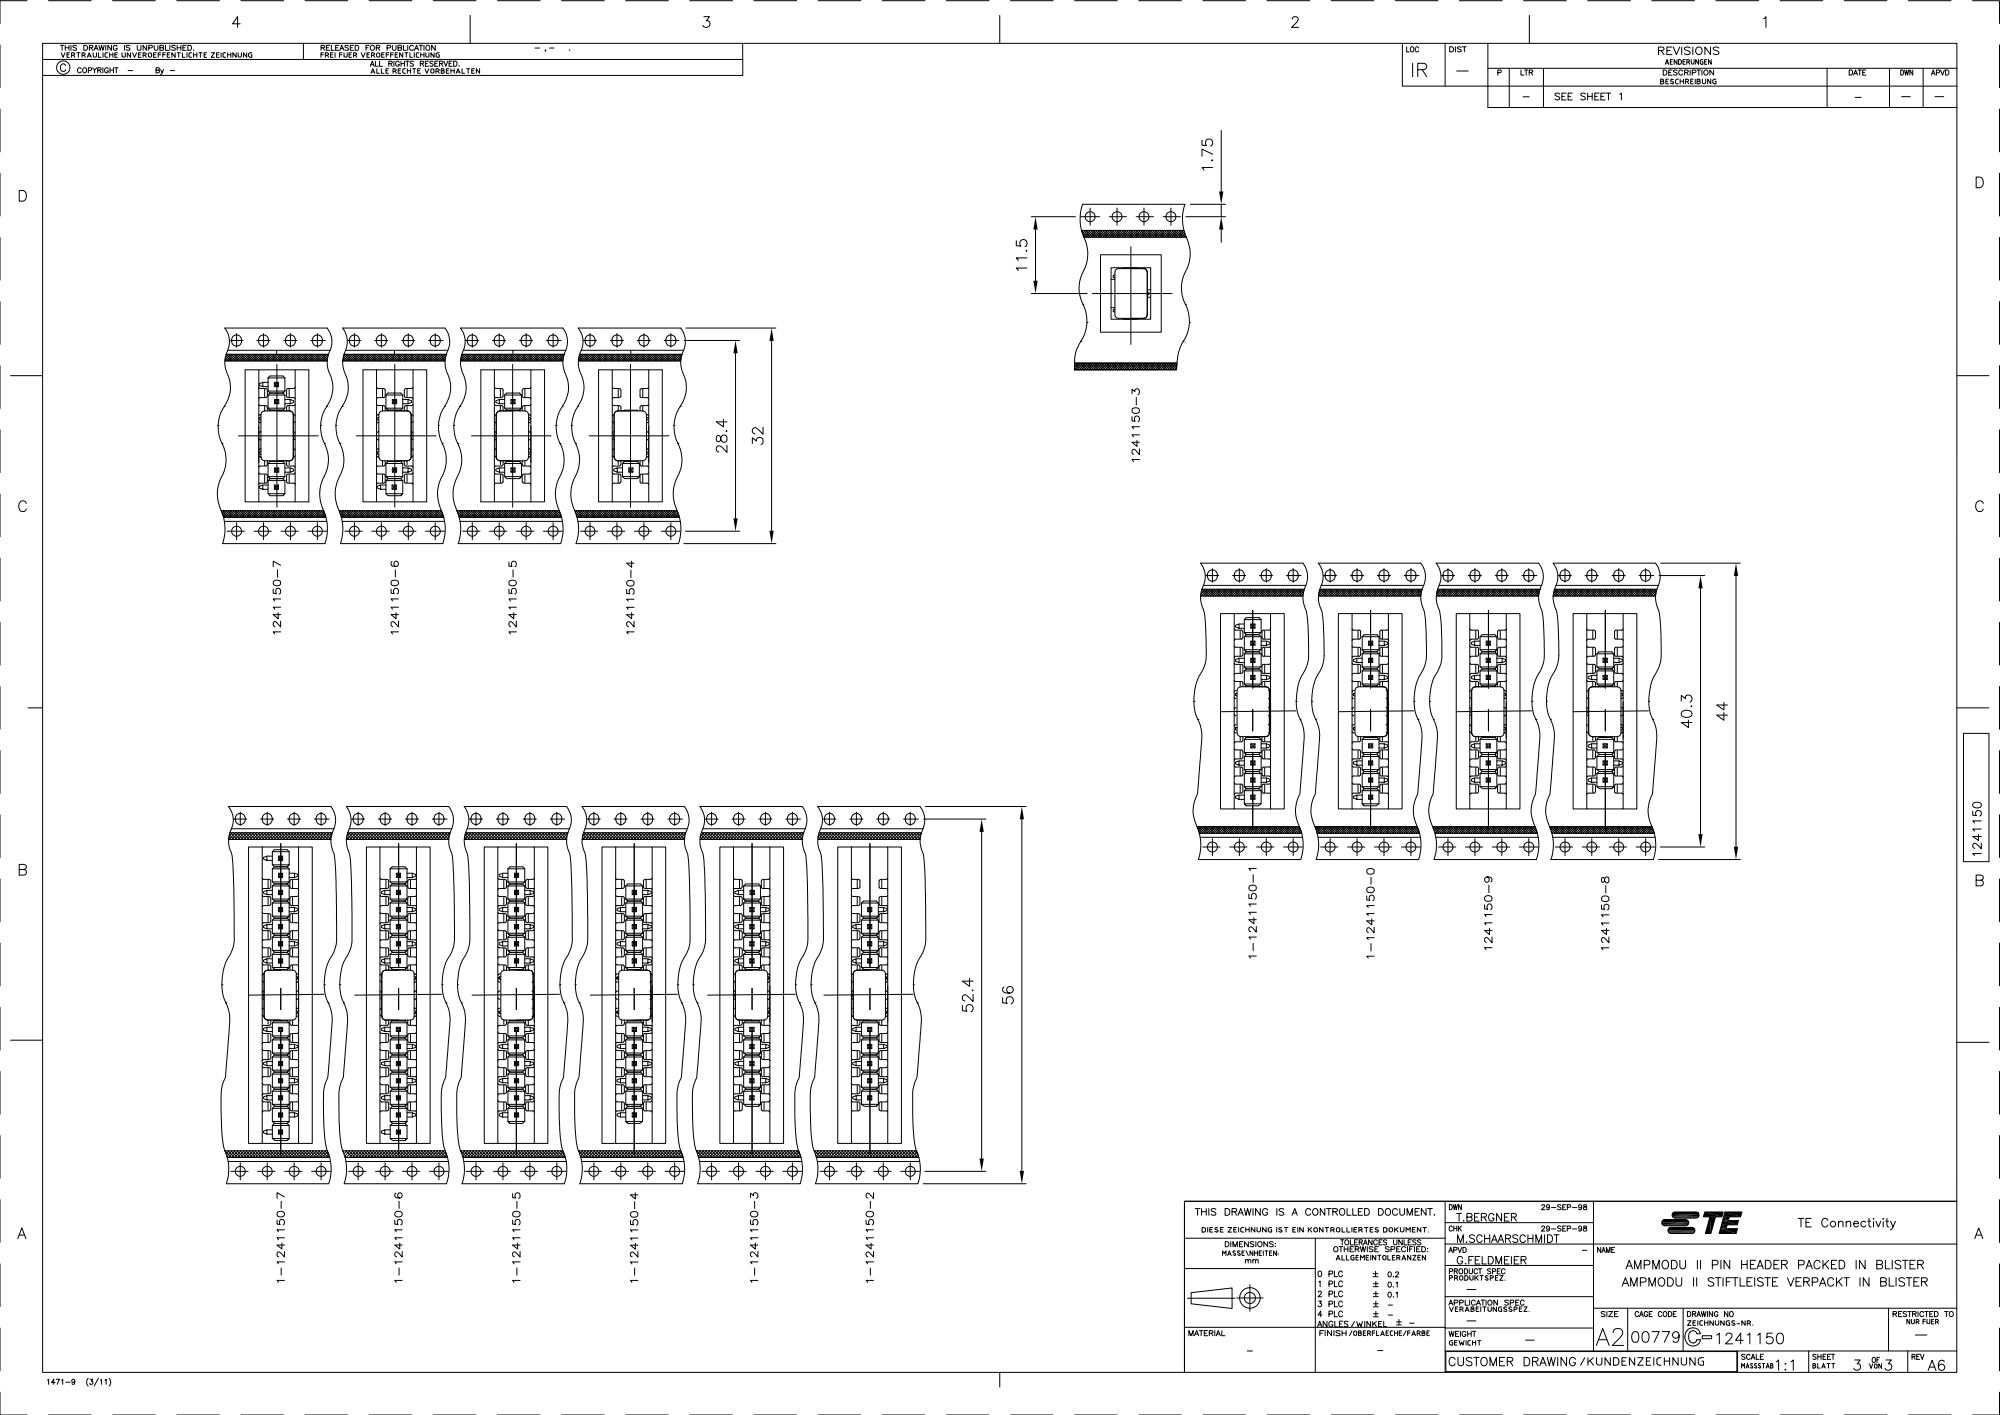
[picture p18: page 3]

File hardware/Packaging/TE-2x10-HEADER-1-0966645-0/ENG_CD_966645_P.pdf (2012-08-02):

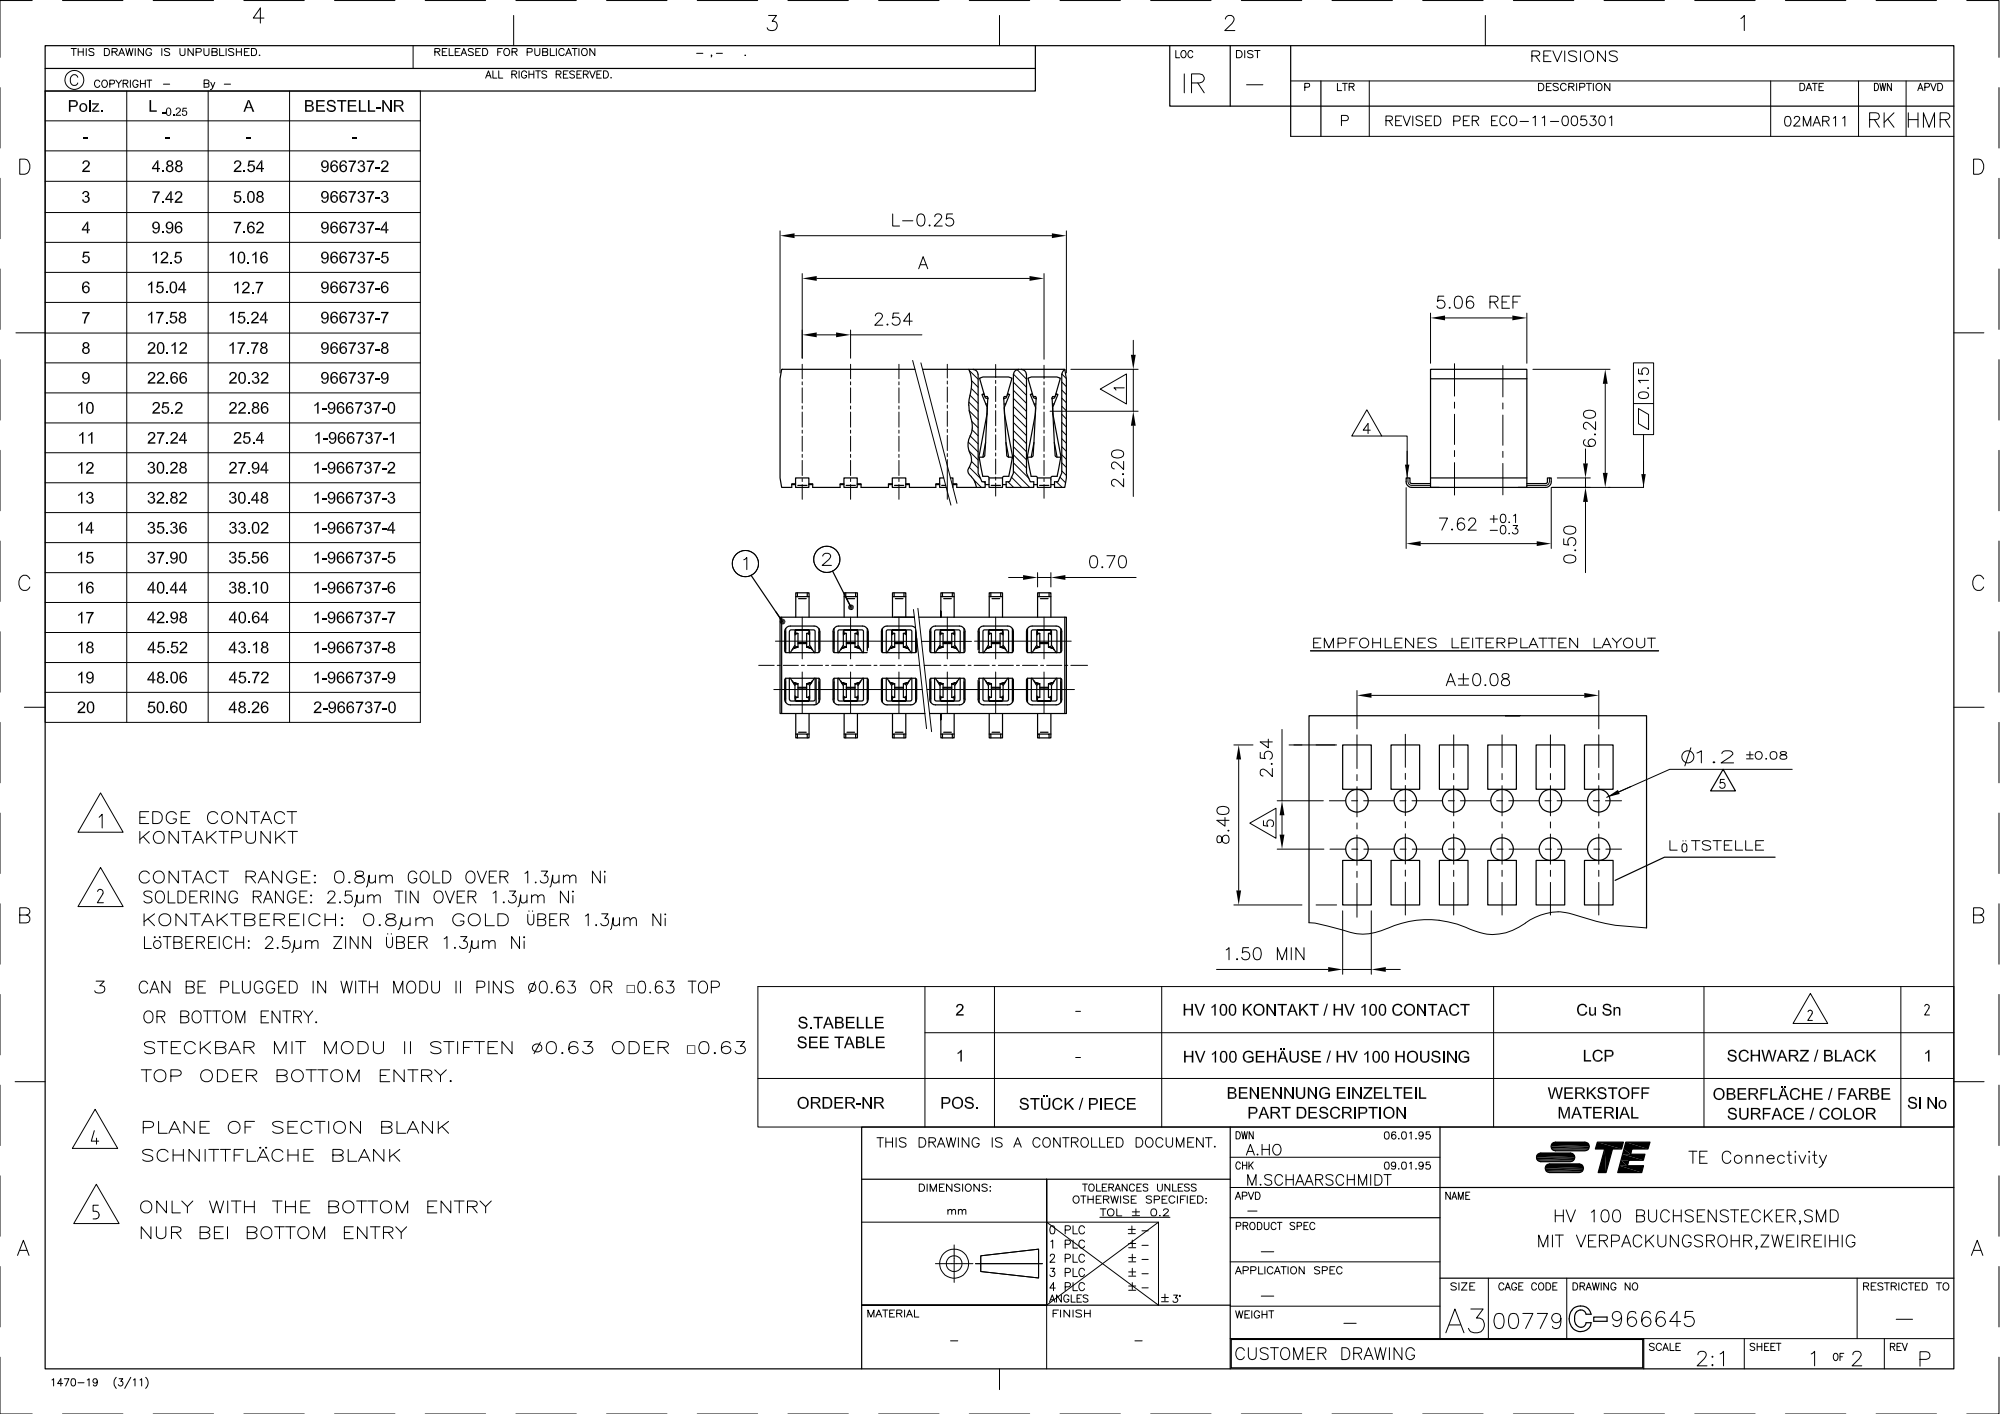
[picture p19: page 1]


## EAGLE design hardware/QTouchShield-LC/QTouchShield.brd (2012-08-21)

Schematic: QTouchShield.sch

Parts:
C1: 10uF/35V; PANASONIC_C
C33, C40, C43, C45, C47, C49, C51: 100nF; 0805
C34, C41, C44, C46, C48, C50, C52: 33nF; 0805
C35, C38: 2.2uF; 1210
C36, C37: 470pF; 0805
C39, C42: 4.7uF; 1210
IC1: AT32UC3C0512CJEDEC-MS-026; LQFP144
J1: SENSOR 00...07; 2X8-V-MALE-SMT-HARWIN
J2: SENSOR 08...15; 2X8-V-MALE-SMT-HARWIN
J3: SENSOR 16...23; 2X8-V-MALE-SMT-HARWIN
J4: SENSOR 24...31; 2X8-V-MALE-SMT-HARWIN
J5: RES 00...07; 2X8-V-FEMALE-SMT-HARWIN
J6: RES 08...15; 2X8-V-FEMALE-SMT-HARWIN
J7: RES 16...23; 2X8-V-FEMALE-SMT-HARWIN
J8: RES 24...31; 2X8-V-FEMALE-SMT-HARWIN
J9: CAP 00...07; 2X8-V-FEMALE-SMT-HARWIN
J10: CAP 08...15; 2X8-V-FEMALE-SMT-HARWIN
J11: CAP 16...23; 2X8-V-FEMALE-SMT-HARWIN
J12: CAP 24...31; 2X8-V-FEMALE-SMT-HARWIN
J13: SPI-MEGA; 2X4-V-MALE-SMT-HARWIN
J14: SPI-UNO; 2X4-V-MALE-SMT-HARWIN
J15: COMMS Select; 2X8-V-MALE-SMT-HARWIN
J16: DETECT00...15; 2X8-V-MALE-SMT-HARWIN
J17: DETECT16...31; 2X8-V-MALE-SMT-HARWIN
J18: JTAG; 2X5-V-MALE-SMT-HARWIN
J19: TOUCH DATA; 2X5-V-MALE-SMT-HARWIN
JP1: COMMS_SELECT; 1X03
LED1: Yellow; LED-1206
LED2: Green; LED-1206
Q1, Q2, Q3, Q4, Q5, Q6: BSS138; SOT23-3
R1, R2: 39R; 0805
R33, R34: 470Ohm; 0805
R35: 10K; 0805
S1: RESET; TACTILE_SWITCH_SMD
SJ5: RESET-LINK; SJ
U1: ARDUINO-2560-MEGA-R3-SMD; ARDUINO-2560-R3-SMD
X1: Firmware Upgrade Port; PN87520

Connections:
ADCVREFN: C51.1, C52.1, IC1.35 (ADCVREFN)
ADCVREFP: C51.2, C52.2, IC1.34 (ADCVREFP)
ADT-SPI0-MISO: J13.2, J14.2, Q3.2 (S)
ADT-SPI0-MOSI: J13.4, J14.4, Q4.2 (S)
ADT-SPI0-SCK: J13.6, J14.6, Q2.2 (S)
ADT-SPI0-SS: J13.8, J14.8, Q1.2 (S)
ADT-USART0-RXD: J15.4, J15.8, J15.12, J15.16, Q5.2 (S)
ADT-USART0-TXD: J15.2, J15.6, J15.10, J15.14, Q6.2 (S)
ARDUINO_RESET: SJ5.1, U1.RESET
GND: C1.-, C33.2, C34.2, C35.2, C36.2, C37.2, C38.2, C39.2, C40.2, C41.2, C42.2, C43.2, C44.2, C45.2, C46.2, C47.2, C48.2, C49.2, C50.2, IC1.6 (GNDIO1), IC1.37 (GNDANA), IC1.52 (GNDPLL), IC1.56 (GNDCORE), IC1.76 (GNDIO2), IC1.104 (GNDIO3-1), IC1.119 (GNDIO3-2), J1.2, J1.4, J1.6, J1.8, J1.10, J1.12, J1.14, J1.16, J2.2, J2.4, J2.6, J2.8, J2.10, J2.12, J2.14, J2.16, J3.2, J3.4, J3.6, J3.8, J3.10, J3.12, J3.14, J3.16, J4.2, J4.4, J4.6, J4.8, J4.10, J4.12, J4.14, J4.16, J18.2, J18.10, J19.9, JP1.3, LED1.C, LED2.C, S1.1, S1.2, U1.GND_1, U1.GND_2, X1.4
IOREF: Q1.1 (G), Q2.1 (G), Q3.1 (G), Q4.1 (G), Q5.1 (G), Q6.1 (G), U1.IOREF
JTAG_RESET: IC1.142 (RESET_N), J18.6, R35.2, S1.3, S1.4, SJ5.2
JTAG_TCK: IC1.1 (PA00), J18.1
JTAG_TDI: IC1.2 (PA01), J18.9
JTAG_TDO: IC1.3 (PA02), J18.3
JTAG_TMS: IC1.4 (PA03), J18.5
MISO-MEGA: J13.1, U1.50
MISO-UNO: J14.1, U1.PWM12 (12)
MOSI-MEGA: J13.3, U1.51
MOSI-UNO: J14.3, U1.PWM11 (11)
unnamed: LED1.A, R33.1
unnamed: J4.15, J8.16
unnamed: J4.13, J8.14
unnamed: J4.11, J8.12
unnamed: J4.9, J8.10
unnamed: J4.7, J8.8
unnamed: J4.5, J8.6
unnamed: J4.3, J8.4
unnamed: J4.1, J8.2
unnamed: J3.15, J7.16
unnamed: J3.13, J7.14
unnamed: J3.11, J7.12
unnamed: J3.9, J7.10
unnamed: J3.7, J7.8
unnamed: J3.5, J7.6
unnamed: J3.3, J7.4
unnamed: J3.1, J7.2
unnamed: J2.15, J6.16
unnamed: J2.13, J6.14
unnamed: J2.11, J6.12
unnamed: J2.9, J6.10
unnamed: J2.7, J6.8
unnamed: J2.5, J6.6
unnamed: J2.3, J6.4
unnamed: J2.1, J6.2
unnamed: J1.15, J5.16
unnamed: J1.13, J5.14
unnamed: J1.11, J5.12
unnamed: J1.9, J5.10
unnamed: J1.7, J5.8
unnamed: J1.5, J5.6
unnamed: J1.3, J5.4
unnamed: J1.1, J5.2
unnamed: R1.2, X1.2
unnamed: R2.2, X1.3
unnamed: LED2.A, R34.1
QT-DETECT-GENERAL: IC1.21 (PA04), R33.2
RX0: J15.3, U1.RX_PWM00 (0(RX0))
RX1: J15.15, U1.RX1_19 (19(RX1))
RX2: J15.11, U1.RX2_17 (17(RX2))
RX3: J15.7, U1.RX3_15 (15(RX3))
SCK-MEGA: J13.5, U1.52
SCK-UNO: J14.5, U1.PWM13 (13)
SDT-SPI0-MISO: IC1.112 (PD05), Q3.3 (D)
SDT-SPI0-MOSI: IC1.111 (PD04), Q4.3 (D)
SDT-SPI0-SCK: IC1.113 (PD06), Q2.3 (D)
SDT-SPI0-SS: IC1.110 (PD03), Q1.3 (D)
SDT-USART0-RXD: IC1.108 (PD01), Q6.3 (D)
SDT-USART0-TXD: IC1.107 (PD00), Q5.3 (D)
SHIELD-DATA-TRANSFER-COM-SELECT: IC1.109 (PD02), JP1.2
SHIELD-DATA-TRANSFER-VISUAL-OUTPUT: IC1.22 (PA05), R34.2
SHIELD-DETECT0: IC1.23 (PA06), J16.1
SHIELD-DETECT1: IC1.24 (PA07), J16.2
SHIELD-DETECT2: IC1.25 (PA08), J16.3
SHIELD-DETECT3: IC1.26 (PA09), J16.4
SHIELD-DETECT4: IC1.27 (PA10), J16.5
SHIELD-DETECT5: IC1.28 (PA11), J16.6
SHIELD-DETECT6: IC1.29 (PA12), J16.7
SHIELD-DETECT7: IC1.30 (PA13), J16.8
SHIELD-DETECT8: IC1.31 (PA14), J16.9
SHIELD-DETECT9: IC1.32 (PA15), J16.10
SHIELD-DETECT10: IC1.33 (PA16), J16.11
SHIELD-DETECT11: IC1.36 (PA19), J16.12
SHIELD-DETECT12: IC1.39 (PA20), J16.13
SHIELD-DETECT13: IC1.40 (PA21), J16.14
SHIELD-DETECT14: IC1.41 (PA22), J16.15
SHIELD-DETECT15: IC1.42 (PA23), J16.16
SHIELD-DETECT16: IC1.43 (PA24), J17.15
SHIELD-DETECT17: IC1.44 (PA25), J17.16
SHIELD-DETECT18: IC1.45 (PA26), J17.13
SHIELD-DETECT19: IC1.46 (PA27), J17.14
SHIELD-DETECT20: IC1.47 (PA28), J17.11
SHIELD-DETECT21: IC1.48 (PA29), J17.12
SHIELD-DETECT22: IC1.120 (PD11), J17.9
SHIELD-DETECT23: IC1.121 (PD12), J17.10
SHIELD-DETECT24: IC1.122 (PD13), J17.7
SHIELD-DETECT25: IC1.123 (PD14), J17.8
SHIELD-DETECT26: IC1.124 (PD15), J17.5
SHIELD-DETECT27: IC1.125 (PD16), J17.6
SHIELD-DETECT28: IC1.126 (PD17), J17.3
SHIELD-DETECT29: IC1.127 (PD18), J17.4
SHIELD-DETECT30: IC1.128 (PD19), J17.1
SHIELD-DETECT31: IC1.129 (PD20), J17.2
SNS0: IC1.140 (PB00), J9.1
SNS1: IC1.141 (PB01), J9.3
SNS2: IC1.143 (PB02), J9.5
SNS3: IC1.144 (PB03), J9.7
SNS4: IC1.7 (PB04), J9.9
SNS5: IC1.8 (PB05), J9.11
SNS6: IC1.9 (PB06), J9.13
SNS7: IC1.10 (PB07), J9.15
SNS8: IC1.11 (PB08), J10.1
SNS9: IC1.12 (PB09), J10.3
SNS10: IC1.13 (PB10), J10.5
SNS11: IC1.14 (PB11), J10.7
SNS12: IC1.15 (PB12), J10.9
SNS13: IC1.16 (PB13), J10.11
SNS14: IC1.17 (PB14), J10.13
SNS15: IC1.18 (PB15), J10.15
SNS16: IC1.19 (PB16), J11.1
SNS17: IC1.20 (PB17), J11.3
SNS18: IC1.57 (PB18), J11.5
SNS19: IC1.58 (PB19), J11.7
SNS20: IC1.59 (PB20), J11.9
SNS21: IC1.60 (PB21), J11.11
SNS22: IC1.61 (PB22), J11.13
SNS23: IC1.62 (PB23), J11.15
SNS24: IC1.63 (PB24), J12.1
SNS25: IC1.64 (PB25), J12.3
SNS26: IC1.65 (PB26), J12.5
SNS27: IC1.66 (PB27), J12.7
SNS28: IC1.67 (PB28), J12.9
SNS29: IC1.68 (PB29), J12.11
SNS30: IC1.69 (PB30), J12.13
SNS31: IC1.70 (PB31), J12.15
SNSK0: IC1.71 (PC00), J5.1, J9.2
SNSK1: IC1.72 (PC01), J5.3, J9.4
SNSK2: IC1.73 (PC02), J5.5, J9.6
SNSK3: IC1.74 (PC03), J5.7, J9.8
SNSK4: IC1.77 (PC04), J5.9, J9.10
SNSK5: IC1.78 (PC05), J5.11, J9.12
SNSK6: IC1.79 (PC06), J5.13, J9.14
SNSK7: IC1.80 (PC07), J5.15, J9.16
SNSK8: IC1.81 (PC08), J6.1, J10.2
SNSK9: IC1.82 (PC09), J6.3, J10.4
SNSK10: IC1.83 (PC10), J6.5, J10.6
SNSK11: IC1.84 (PC11), J6.7, J10.8
SNSK12: IC1.85 (PC12), J6.9, J10.10
SNSK13: IC1.86 (PC13), J6.11, J10.12
SNSK14: IC1.87 (PC14), J6.13, J10.14
SNSK15: IC1.88 (PC15), J6.15, J10.16
SNSK16: IC1.89 (PC16), J7.1, J11.2
SNSK17: IC1.90 (PC17), J7.3, J11.4
SNSK18: IC1.91 (PC18), J7.5, J11.6
SNSK19: IC1.92 (PC19), J7.7, J11.8
SNSK20: IC1.93 (PC20), J7.9, J11.10
SNSK21: IC1.94 (PC21), J7.11, J11.12
SNSK22: IC1.95 (PC22), J7.13, J11.14
SNSK23: IC1.96 (PC23), J7.15, J11.16
SNSK24: IC1.97 (PC24), J8.1, J12.2
SNSK25: IC1.98 (PC25), J8.3, J12.4
SNSK26: IC1.99 (PC26), J8.5, J12.6
SNSK27: IC1.100 (PC27), J8.7, J12.8
SNSK28: IC1.101 (PC28), J8.9, J12.10
SNSK29: IC1.102 (PC29), J8.11, J12.12
SNSK30: IC1.105 (PC30), J8.13, J12.14
SNSK31: IC1.106 (PC31), J8.15, J12.16
SS-MEGA: J13.7, U1.53
SS-UNO: J14.7, U1.PWM10 (10)
TOUCH_DATA-MISO: IC1.133 (PD24), J19.7
TOUCH_DATA-MOSI: IC1.132 (PD23), J19.6
TOUCH_DATA-SCK: IC1.131 (PD22), J19.8
TOUCH_DATA-SS: IC1.130 (PD21), J19.5
TX0: J15.1, U1.TX_PWM01 (1(TX0))
TX1: J15.13, U1.TX1_18 (18(TX1))
TX2: J15.9, U1.TX2_16 (16(TX2))
TX3: J15.5, U1.TX3_14 (14(TX3))
USB-DM: IC1.50 (DM), R1.1
USB-DP: IC1.51 (DP), R2.1
VCC: C1.+, C33.1, C34.1, C39.1, C40.1, C41.1, C42.1, C43.1, C44.1, C45.1, C46.1, C47.1, C48.1, C49.1, C50.1, IC1.5 (VDDIO1), IC1.38 (VDDANA), IC1.53 (VDDIN_5), IC1.75 (VDDIO2), IC1.103 (VDDIO3-1), IC1.118 (VDDIO3-2), J18.4, J19.10, JP1.1, R35.1, U1.5V_1, X1.1
VDDCORE: C37.1, C38.1, IC1.55 (VDDCORE)
VDDIN_33: C35.1, C36.1, IC1.54 (VDDIN_33)

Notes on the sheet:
SNSK Lines
JTAG
SNS Lines
Detect Output Bus
SHIELD-DATA-TRANSFER
UART-COMS
Mount close to pins 55 & 56
Keep close to pin 5
Keep close to pin 75
Keep close to pin 103
Keep close to
pin 118
Keep close to pin 53
Keep close to pins 34 & 35
Sensor Headers
Detection
Use jumper pair to
select alternative
UART interface
Select between
SPI and UART
Date: 1st August 2012
Revision: 0.1
Author: Stuart Cording
aka /*CODINGHEAD*/
Designed for use with the
Arduino[TM] MEGA 2560 r3
Project: QTouchShield-LC
Keep close to pins 37 & 38
Decoupling capacitors
Supply decoupling capacitors
R35 not mounted
(Only req. when
Arduino is *not*
Use to link AT32UC3C
RESET_N to
Arduino RESET
Mountain View, California, 94041, USA.
Creative Commons, 444 Castro Street, Suite 900,
http://creativecommons.org/licenses/by-sa/3.0/ or send a letter to:

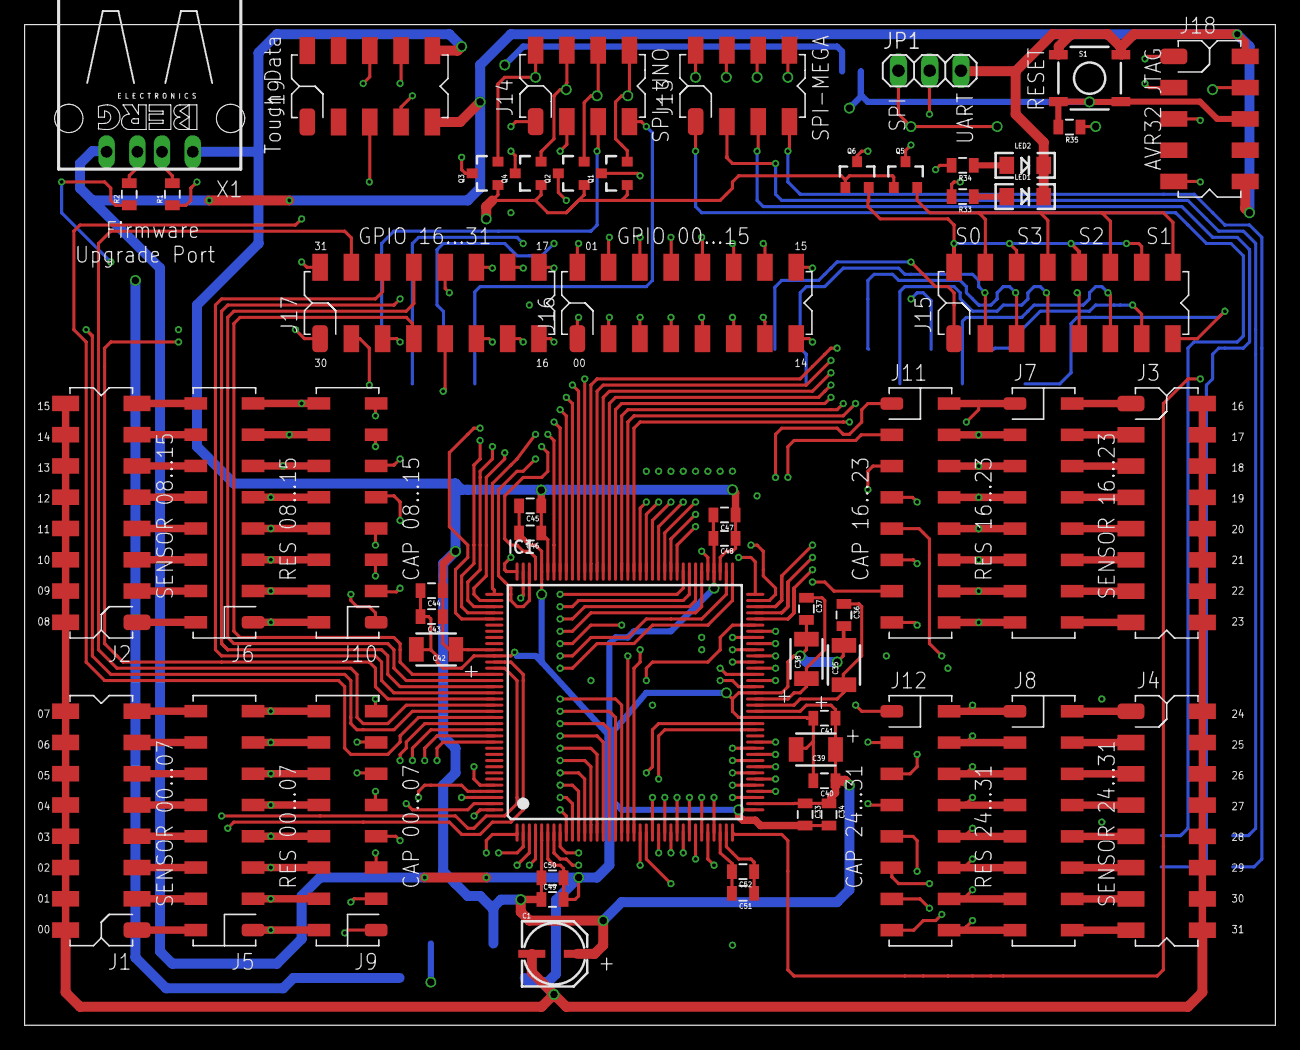
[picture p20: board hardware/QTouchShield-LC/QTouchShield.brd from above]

Board: 4 copper layers, 101.6 x 81.3 mm, 59 parts (1 on the bottom side), 182 nets.

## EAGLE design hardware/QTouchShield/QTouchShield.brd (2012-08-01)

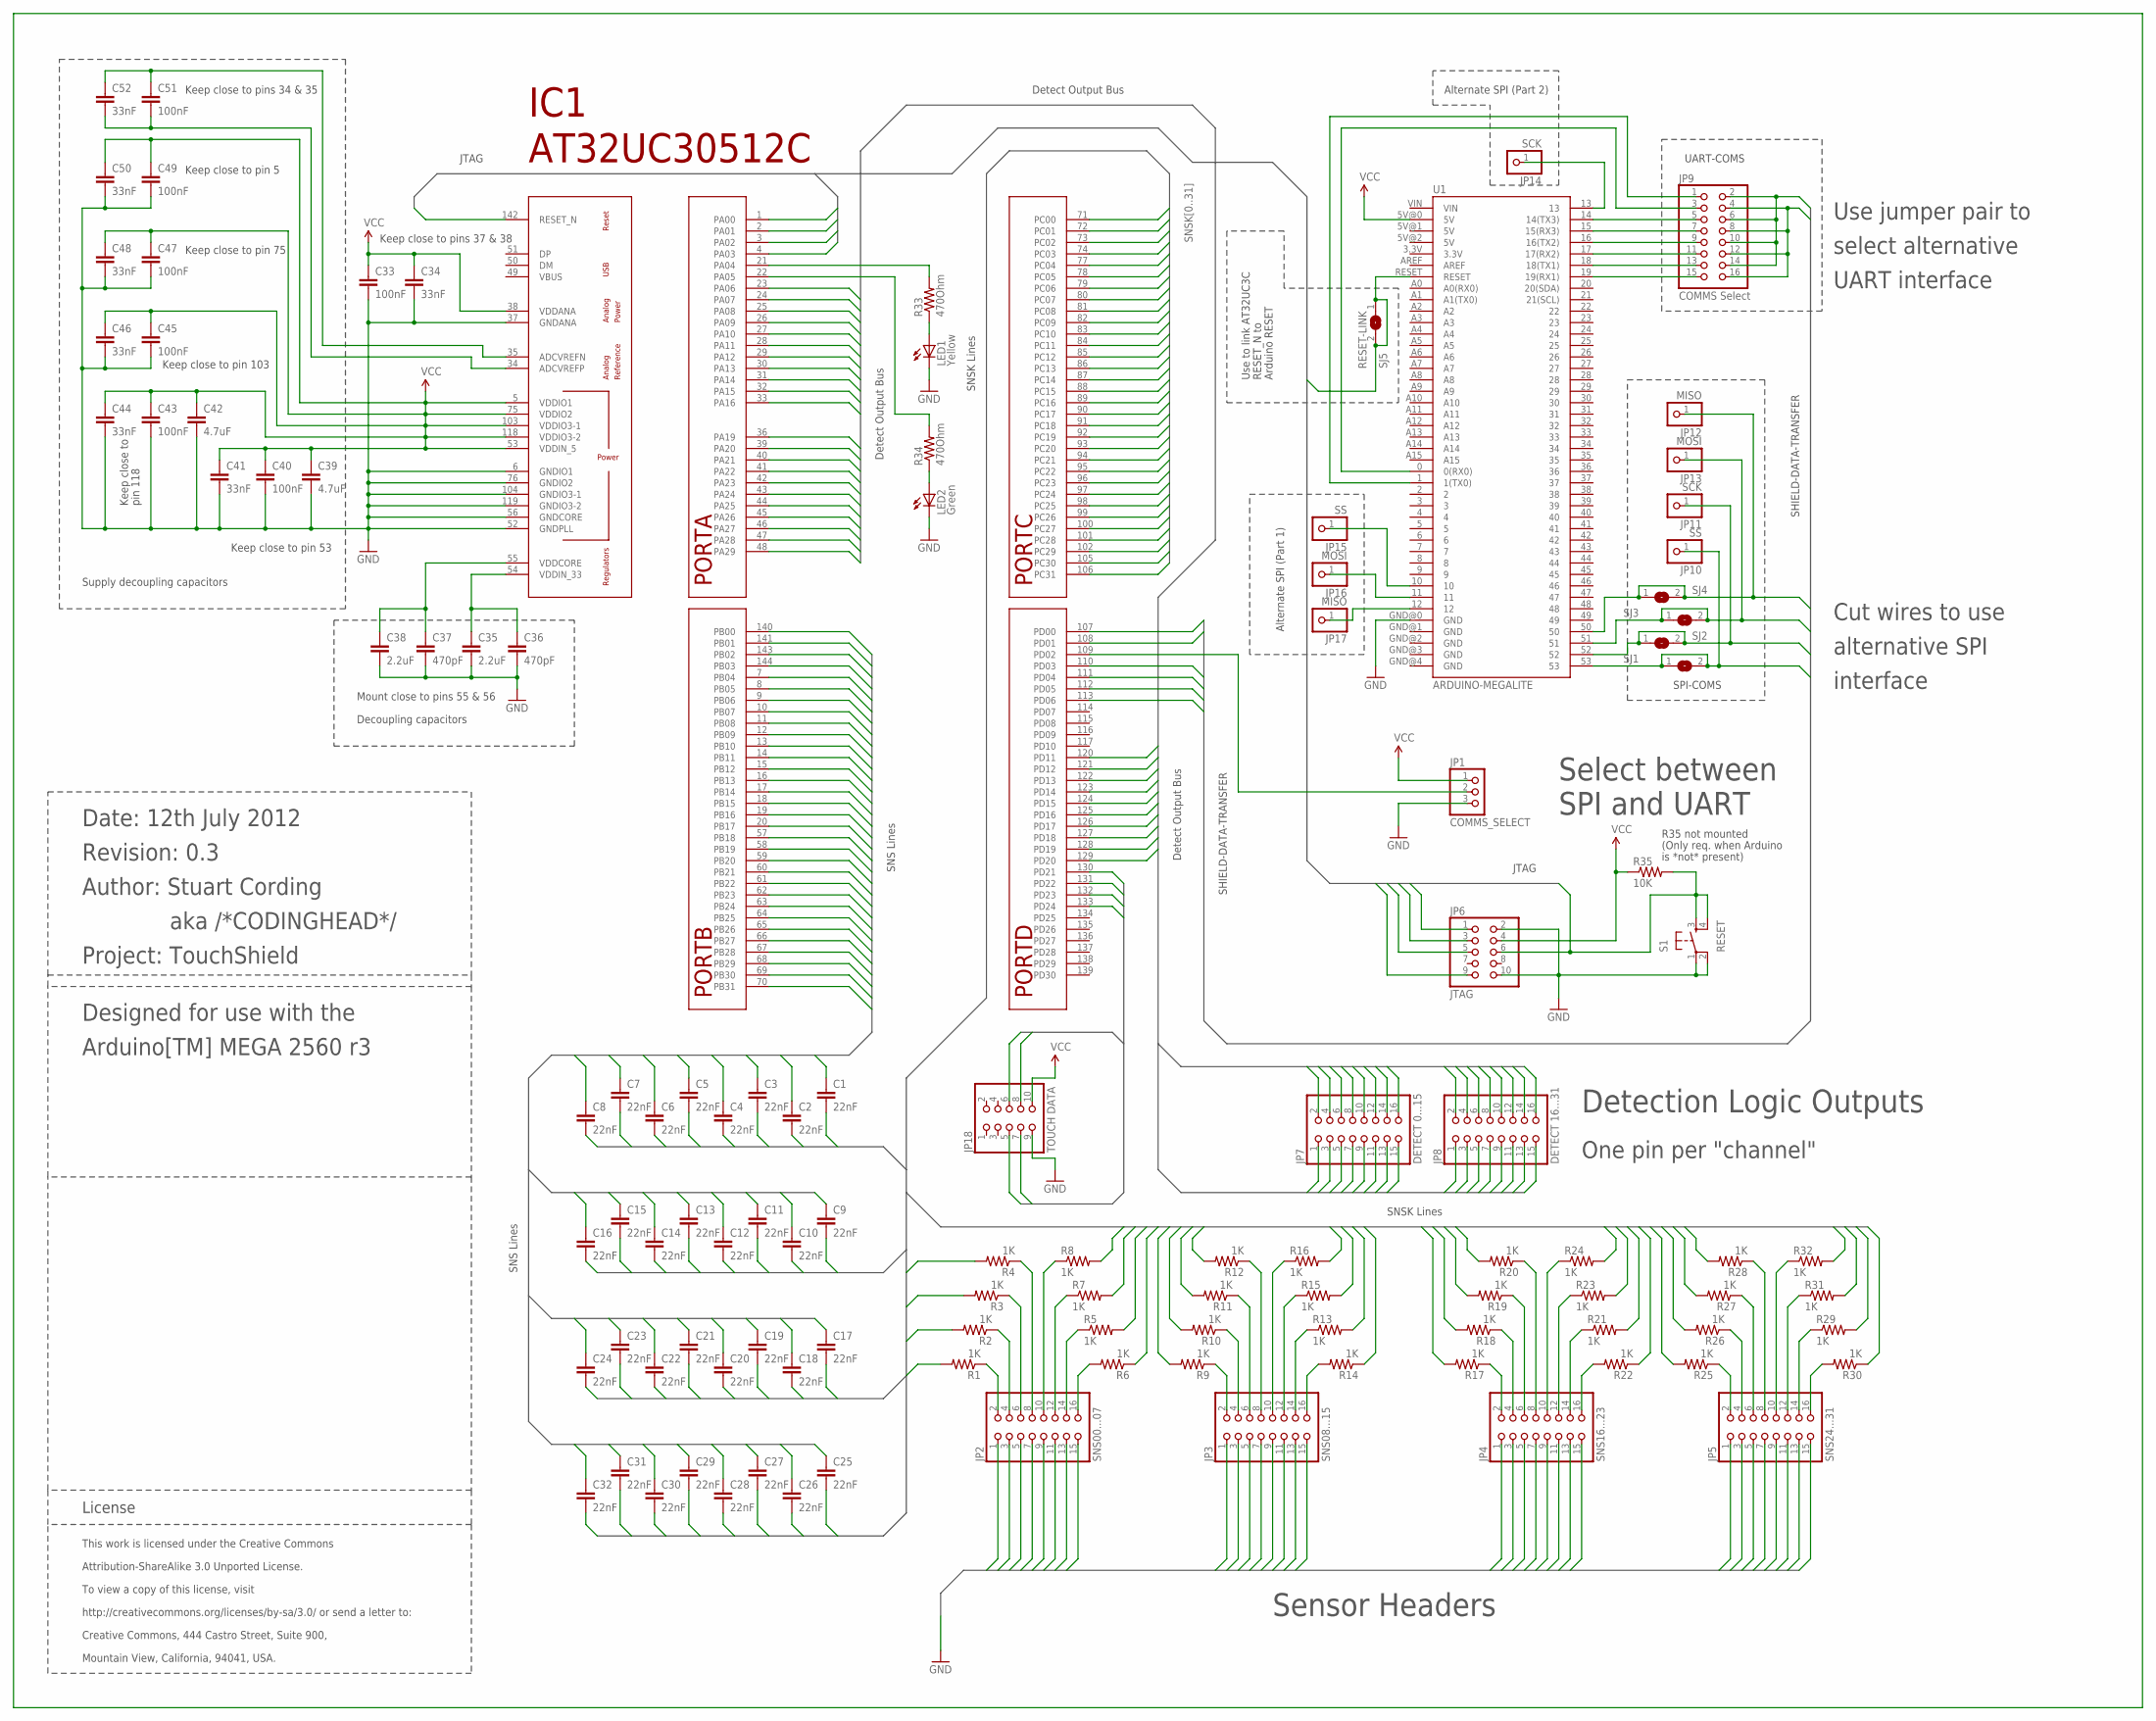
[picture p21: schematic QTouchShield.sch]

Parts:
C1, C2, C3, C4, C5, C6, C7, C8, C9, C10, C11, C12, C13, C14, C15, C16, C17, C18, C19, C20, C21, C22, C23, C24, C25, C26, C27, C28, C29, C30, C31, C32: 22nF; 0805
C33, C40, C43, C45, C47, C49, C51: 100nF; 0805
C34, C41, C44, C46, C48, C50, C52: 33nF; 0805
C35, C38: 2.2uF; 1210
C36, C37: 470pF; 0805
C39, C42: 4.7uF; 1210
IC1: AT32UC3C0512CJEDEC-MS-026; LQFP144
JP1: COMMS_SELECT; 1X03
JP2: SNS00...07; 2X08
JP3: SNS08...15; 2X08
JP4: SNS16...23; 2X08
JP5: SNS24...31; 2X08
JP6: JTAG; 2X05
JP7: DETECT 0...15; 2X08
JP8: DETECT 16...31; 2X08
JP9: COMMS Select; 2X08
JP10, JP15: SS; 1X01
JP11, JP14: SCK; 1X01
JP12, JP17: MISO; 1X01
JP13, JP16: MOSI; 1X01
JP18: TOUCH DATA; 2X05
LED1: Yellow; LED-1206
LED2: Green; LED-1206
R1, R2, R3, R4, R5, R6, R7, R8, R9, R10, R11, R12, R13, R14, R15, R16, R17, R18, R19, R20, R21, R22, R23, R24, R25, R26, R27, R28, R29, R30, R31, R32: 1K; 0805
R33, R34: 470Ohm; 0805
R35: 10K; 0805
S1: RESET; TACTILE_SWITCH_SMD
SJ1, SJ2, SJ3, SJ4: SJ
SJ5: RESET-LINK; SJ
U1: ARDUINO-MEGALITE; ARDUINO_MEGA_LITE

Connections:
ADCVREFN: C51.1, C52.1, IC1.35 (ADCVREFN)
ADCVREFP: C51.2, C52.2, IC1.34 (ADCVREFP)
GND: C33.2, C34.2, C35.2, C36.2, C37.2, C38.2, C39.2, C40.2, C41.2, C42.2, C43.2, C44.2, C45.2, C46.2, C47.2, C48.2, C49.2, C50.2, IC1.6 (GNDIO1), IC1.37 (GNDANA), IC1.52 (GNDPLL), IC1.56 (GNDCORE), IC1.76 (GNDIO2), IC1.104 (GNDIO3-1), IC1.119 (GNDIO3-2), JP1.3, JP2.1, JP2.3, JP2.5, JP2.7, JP2.9, JP2.11, JP2.13, JP2.15, JP3.1, JP3.3, JP3.5, JP3.7, JP3.9, JP3.11, JP3.13, JP3.15, JP4.1, JP4.3, JP4.5, JP4.7, JP4.9, JP4.11, JP4.13, JP4.15, JP5.1, JP5.3, JP5.5, JP5.7, JP5.9, JP5.11, JP5.13, JP5.15, JP6.2, JP6.10, JP18.9, LED1.C, LED2.C, S1.1, S1.2, U1.GND@0 (GND)
JTAG_RESET: IC1.142 (RESET_N), JP6.6, R35.2, S1.3, S1.4, SJ5.1, SJ5.2, U1.RESET
JTAG_TCK: IC1.1 (PA00), JP6.1
JTAG_TDI: IC1.2 (PA01), JP6.9
JTAG_TDO: IC1.3 (PA02), JP6.3
JTAG_TMS: IC1.4 (PA03), JP6.5
unnamed: LED1.A, R33.1
unnamed: JP2.2, R1.1
unnamed: JP2.4, R2.1
unnamed: JP2.6, R3.1
unnamed: JP2.8, R4.1
unnamed: JP2.10, R8.1
unnamed: JP2.12, R7.1
unnamed: JP2.14, R5.1
unnamed: JP2.16, R6.2
unnamed: JP3.2, R9.1
unnamed: JP3.4, R10.1
unnamed: JP3.6, R11.1
unnamed: JP3.8, R12.1
unnamed: JP3.10, R16.1
unnamed: JP3.12, R15.1
unnamed: JP3.14, R13.1
unnamed: JP3.16, R14.2
unnamed: JP4.2, R17.1
unnamed: JP4.4, R18.1
unnamed: JP4.6, R19.1
unnamed: JP4.8, R20.1
unnamed: JP4.10, R24.1
unnamed: JP4.12, R23.1
unnamed: JP4.14, R21.1
unnamed: JP4.16, R22.2
unnamed: JP5.2, R25.1
unnamed: JP5.4, R26.1
unnamed: JP5.6, R27.1
unnamed: JP5.8, R28.1
unnamed: JP5.10, R32.1
unnamed: JP5.12, R31.1
unnamed: JP5.14, R29.1
unnamed: JP5.16, R30.2
unnamed: LED2.A, R34.1
QT-DETECT-GENERAL: IC1.21 (PA04), R33.2
RX0: JP9.3, U1.0 (0(RX0))
RX1: JP9.15, U1.19 (19(RX1))
RX2: JP9.11, U1.17 (17(RX2))
RX3: JP9.7, U1.15 (15(RX3))
SDT-SPI0-MISO: IC1.112 (PD05), JP12.1, SJ4.1, SJ4.2, U1.50
SDT-SPI0-MOSI: IC1.111 (PD04), JP13.1, SJ3.1, SJ3.2, U1.51
SDT-SPI0-SCK: IC1.113 (PD06), JP11.1, SJ2.1, SJ2.2, U1.52
SDT-SPI0-SS: IC1.110 (PD03), JP10.1, SJ1.1, SJ1.2, U1.53
SDT-USART0-RXD: IC1.108 (PD01), JP9.4, JP9.8, JP9.12, JP9.16
SDT-USART0-TXD: IC1.107 (PD00), JP9.2, JP9.6, JP9.10, JP9.14
SHIELD-DATA-TRANSFER-COM-SELECT: IC1.109 (PD02), JP1.2
SHIELD-DATA-TRANSFER-VISUAL-OUTPUT: IC1.22 (PA05), R34.2
SHIELD-DETECT0: IC1.23 (PA06), JP7.1
SHIELD-DETECT1: IC1.24 (PA07), JP7.2
SHIELD-DETECT2: IC1.25 (PA08), JP7.3
SHIELD-DETECT3: IC1.26 (PA09), JP7.4
SHIELD-DETECT4: IC1.27 (PA10), JP7.5
SHIELD-DETECT5: IC1.28 (PA11), JP7.6
SHIELD-DETECT6: IC1.29 (PA12), JP7.7
SHIELD-DETECT7: IC1.30 (PA13), JP7.8
SHIELD-DETECT8: IC1.31 (PA14), JP7.9
SHIELD-DETECT9: IC1.32 (PA15), JP7.10
SHIELD-DETECT10: IC1.33 (PA16), JP7.11
SHIELD-DETECT11: IC1.36 (PA19), JP7.12
SHIELD-DETECT12: IC1.39 (PA20), JP7.13
SHIELD-DETECT13: IC1.40 (PA21), JP7.14
SHIELD-DETECT14: IC1.41 (PA22), JP7.15
SHIELD-DETECT15: IC1.42 (PA23), JP7.16
SHIELD-DETECT16: IC1.43 (PA24), JP8.1
SHIELD-DETECT17: IC1.44 (PA25), JP8.2
SHIELD-DETECT18: IC1.45 (PA26), JP8.3
SHIELD-DETECT19: IC1.46 (PA27), JP8.4
SHIELD-DETECT20: IC1.47 (PA28), JP8.5
SHIELD-DETECT21: IC1.48 (PA29), JP8.6
SHIELD-DETECT22: IC1.120 (PD11), JP8.7
SHIELD-DETECT23: IC1.121 (PD12), JP8.8
SHIELD-DETECT24: IC1.122 (PD13), JP8.9
SHIELD-DETECT25: IC1.123 (PD14), JP8.10
SHIELD-DETECT26: IC1.124 (PD15), JP8.11
SHIELD-DETECT27: IC1.125 (PD16), JP8.12
SHIELD-DETECT28: IC1.126 (PD17), JP8.13
SHIELD-DETECT29: IC1.127 (PD18), JP8.14
SHIELD-DETECT30: IC1.128 (PD19), JP8.15
SHIELD-DETECT31: IC1.129 (PD20), JP8.16
SNS0: C1.1, IC1.140 (PB00)
SNS1: C2.1, IC1.141 (PB01)
SNS2: C3.1, IC1.143 (PB02)
SNS3: C4.1, IC1.144 (PB03)
SNS4: C5.1, IC1.7 (PB04)
SNS5: C6.1, IC1.8 (PB05)
SNS6: C7.1, IC1.9 (PB06)
SNS7: C8.1, IC1.10 (PB07)
SNS8: C9.1, IC1.11 (PB08)
SNS9: C10.1, IC1.12 (PB09)
SNS10: C11.1, IC1.13 (PB10)
SNS11: C12.1, IC1.14 (PB11)
SNS12: C13.1, IC1.15 (PB12)
SNS13: C14.1, IC1.16 (PB13)
SNS14: C15.1, IC1.17 (PB14)
SNS15: C16.1, IC1.18 (PB15)
SNS16: C17.1, IC1.19 (PB16)
SNS17: C18.1, IC1.20 (PB17)
SNS18: C19.1, IC1.57 (PB18)
SNS19: C20.1, IC1.58 (PB19)
SNS20: C21.1, IC1.59 (PB20)
SNS21: C22.1, IC1.60 (PB21)
SNS22: C23.1, IC1.61 (PB22)
SNS23: C24.1, IC1.62 (PB23)
SNS24: C25.1, IC1.63 (PB24)
SNS25: C26.1, IC1.64 (PB25)
SNS26: C27.1, IC1.65 (PB26)
SNS27: C28.1, IC1.66 (PB27)
SNS28: C29.1, IC1.67 (PB28)
SNS29: C30.1, IC1.68 (PB29)
SNS30: C31.1, IC1.69 (PB30)
SNS31: C32.1, IC1.70 (PB31)
SNSK0: C1.2, IC1.71 (PC00), R1.2
SNSK1: C2.2, IC1.72 (PC01), R2.2
SNSK2: C3.2, IC1.73 (PC02), R3.2
SNSK3: C4.2, IC1.74 (PC03), R4.2
SNSK4: C5.2, IC1.77 (PC04), R8.2
SNSK5: C6.2, IC1.78 (PC05), R7.2
SNSK6: C7.2, IC1.79 (PC06), R5.2
SNSK7: C8.2, IC1.80 (PC07), R6.1
SNSK8: C9.2, IC1.81 (PC08), R9.2
SNSK9: C10.2, IC1.82 (PC09), R10.2
SNSK10: C11.2, IC1.83 (PC10), R11.2
SNSK11: C12.2, IC1.84 (PC11), R12.2
SNSK12: C13.2, IC1.85 (PC12), R16.2
SNSK13: C14.2, IC1.86 (PC13), R15.2
SNSK14: C15.2, IC1.87 (PC14), R13.2
SNSK15: C16.2, IC1.88 (PC15), R14.1
SNSK16: C17.2, IC1.89 (PC16), R17.2
SNSK17: C18.2, IC1.90 (PC17), R18.2
SNSK18: C19.2, IC1.91 (PC18), R19.2
SNSK19: C20.2, IC1.92 (PC19), R20.2
SNSK20: C21.2, IC1.93 (PC20), R24.2
SNSK21: C22.2, IC1.94 (PC21), R23.2
SNSK22: C23.2, IC1.95 (PC22), R21.2
SNSK23: C24.2, IC1.96 (PC23), R22.1
SNSK24: C25.2, IC1.97 (PC24), R25.2
SNSK25: C26.2, IC1.98 (PC25), R26.2
SNSK26: C27.2, IC1.99 (PC26), R27.2
SNSK27: C28.2, IC1.100 (PC27), R28.2
SNSK28: C29.2, IC1.101 (PC28), R32.2
SNSK29: C30.2, IC1.102 (PC29), R31.2
SNSK30: C31.2, IC1.105 (PC30), R29.2
SNSK31: C32.2, IC1.106 (PC31), R30.1
SPI-MISO-ALT: JP17.1, U1.12
SPI-MOSI-ALT: JP16.1, U1.11
SPI-SCK-ALT: JP14.1, U1.13
SPI-SS-ALT: JP15.1, U1.10
TOUCH_DATA-MISO: IC1.133 (PD24), JP18.7
TOUCH_DATA-MOSI: IC1.132 (PD23), JP18.6
TOUCH_DATA-SCK: IC1.131 (PD22), JP18.8
TOUCH_DATA-SS: IC1.130 (PD21), JP18.5
TX0: JP9.1, U1.1 (1(TX0))
TX1: JP9.13, U1.18 (18(TX1))
TX2: JP9.9, U1.16 (16(TX2))
TX3: JP9.5, U1.14 (14(TX3))
VCC: C33.1, C34.1, C39.1, C40.1, C41.1, C42.1, C43.1, C44.1, C45.1, C46.1, C47.1, C48.1, C49.1, C50.1, IC1.5 (VDDIO1), IC1.38 (VDDANA), IC1.53 (VDDIN_5), IC1.75 (VDDIO2), IC1.103 (VDDIO3-1), IC1.118 (VDDIO3-2), JP1.1, JP6.4, JP18.10, R35.1, U1.5V@0 (5V)
VDDCORE: C37.1, C38.1, IC1.55 (VDDCORE)
VDDIN_33: C35.1, C36.1, IC1.54 (VDDIN_33)

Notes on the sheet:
SNSK Lines
JTAG
SNS Lines
Detect Output Bus
SHIELD-DATA-TRANSFER
UART-COMS
SPI-COMS
Mount close to pins 55 & 56
Keep close to pin 5
Keep close to pin 75
Keep close to pin 103
Keep close to
pin 118
Keep close to pin 53
Keep close to pins 34 & 35
Sensor Headers
Detection Logic Outputs
Cut wires to use
alternative SPI
interface
Use jumper pair to
select alternative
UART interface
Select between
SPI and UART
Date: 12th July 2012
Revision: 0.3
Author: Stuart Cording
aka /*CODINGHEAD*/
Designed for use with the
Arduino[TM] MEGA 2560 r3
Project: TouchShield
Keep close to pins 37 & 38
Decoupling capacitors
Supply decoupling capacitors
Alternate SPI (Part 2)
Alternate SPI (Part 1)
R35 not mounted
(Only req. when Arduino
is *not* present)

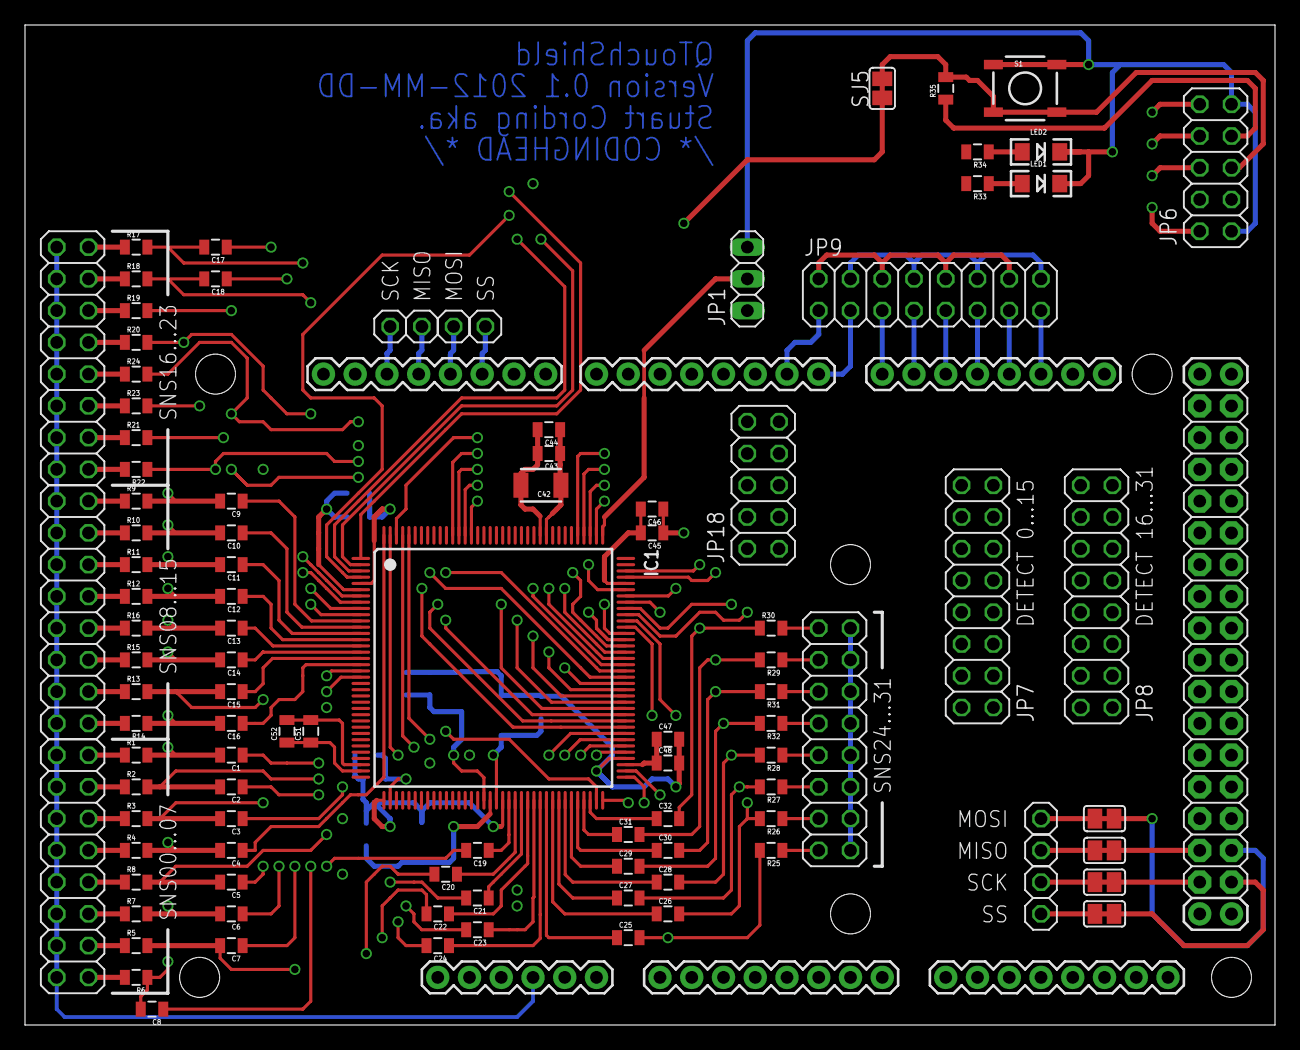
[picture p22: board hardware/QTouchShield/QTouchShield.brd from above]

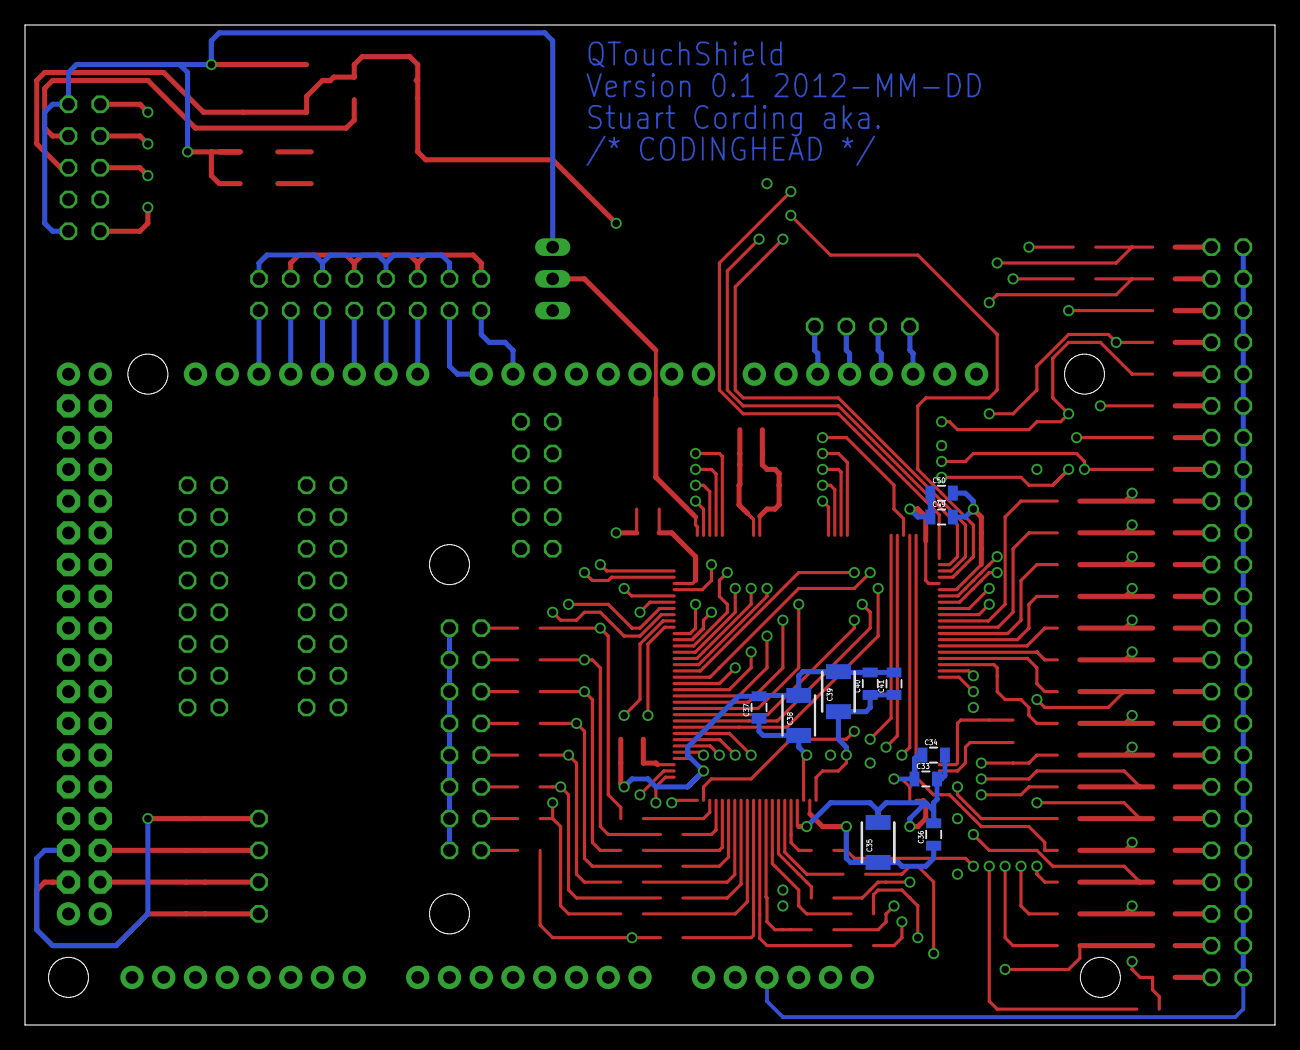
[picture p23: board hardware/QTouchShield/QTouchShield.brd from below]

Board: 4 copper layers, 100.0 x 80.0 mm, 115 parts (11 on the bottom side), 166 nets.

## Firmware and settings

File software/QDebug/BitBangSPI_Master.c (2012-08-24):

/* This source file is part of the ATMEL QTouch Library Release 4.4 */
/******************************************************************************
 *
 * \file
 *
 * \brief  This file contains the BitBangSPI Configuration settings.
 *
 * - Compiler:           IAR EWAVR and GNU GCC for AVR32
 * - Supported devices:  AT32UC3A0/A1 Series, AT32UC3B0/B1 Series 
 *                       AND AT32UC3C0/C1 Series 
 * - Userguide:          QTouch Library User Guide - doc8207.pdf.
 * - Support email:      touch@atmel.com
 *
 * \author               Atmel Corporation: http://www.atmel.com \n
 *                       Support and FAQ: http://support.atmel.no/
 *
 *   Copyright (c) 2010, Atmel Corporation All rights reserved.
 *  
 * \asf_license_start
 *
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
 * 3. The name of Atmel may not be used to endorse or promote products derived
 *    from this software without specific prior written permission.
 *
 * 4. This software may only be redistributed and used in connection with an
 *    Atmel microcontroller product.
 *
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
 * \asf_license_stop
 *
 ******************************************************************************/


/*============================ INCLUDES ======================================*/

#include "parts.h"
#include "BitBangSPI_Master.h"
#include "QDebugTransport.h"

#ifdef _DEBUG_INTERFACE_

#if defined(__ICCAVR32__)
 #include "intrinsics.h"
#endif


#define PORTA (((volatile avr32_gpio_port_t *) &AVR32_GPIO) + 0)
#define PORTB (((volatile avr32_gpio_port_t *) &AVR32_GPIO) + 1)
#define PORTC (((volatile avr32_gpio_port_t *) &AVR32_GPIO) + 2)

#if (UC3A0 || UC3A1 || UC3B)
#define PORTX (((volatile avr32_gpio_port_t *) &AVR32_GPIO) + 3)
#elif UC3C
#define PORTD (((volatile avr32_gpio_port_t *) &AVR32_GPIO) + 3)
#else
# error Unsupported chip type
#endif




/*============================ IMPLEMENTATION ================================*/

/*============================================================================
Name    :   BitBangSPI_Master_Init
------------------------------------------------------------------------------
Purpose :   Initialize BitBangSPI Interface
Input   :   n/a
Output  :   n/a
Notes   :	Called from QDebug_Init in QDebug.c
============================================================================*/
void BitBangSPI_Master_Init (void)
{
    // Set the Slave Select pin - pin is active low. This ensures that the
    // pin is logic high when we configure it.
    REG( PORT, SPI_BB_SS )->ovrs =  ((1<<SS_BB) );
    
    // Enable output drivers for SS, MOSI and SCK pins
    REG( PORT, SPI_BB_SS )->oders =  ((1<<SS_BB) );
    REG( PORT, SPI_BB_MOSI )->oders =  (( 1 << MOSI_BB ) );
    REG( PORT, SPI_BB_SCK )->oders =  ( ( 1 << SCK_BB ));

    // Disable output drivers for MISO pin (input)
    REG( PORT, SPI_BB_MISO )->oderc =  ( 1 << MISO_BB );

    //REG( PORT, SPI_BB_SS )->ovrc =  ((1<<SS_BB) );
    
    // MOSI is low when inactive
    REG( PORT, SPI_BB_MOSI )->ovrc =  (( 1 << MOSI_BB ) );
    
    // CLK is low when inactive
    REG( PORT, SPI_BB_SCK )->ovrc =  ( ( 1 << SCK_BB ));

    // Don't know what this does yet
    REG( PORT, SPI_BB_MISO )->ovrs =  ( 1 << MISO_BB );
}

/*============================================================================
Name    :   BitBangSPI_Send_Byte
------------------------------------------------------------------------------
Purpose :   Send and Read one byte using BitBangSPI Interface
Input   :   Data to send to slave
Output  :   Data read from slave
Notes   :	Called from BitBangSPI_Send_Message in this file
============================================================================*/
uint8_t BitBangSPI_Send_Byte(uint8_t c)
{
    unsigned bit;
    
    // Data is sent on:
    //  - CLK trailing edge
    //  - MSbit first
    
    for (bit = 0; bit < 8; bit++) {
        /* write MOSI on trailing edge of previous clock */
        if (c & 0x80)
            REG( PORT, SPI_BB_MOSI )->ovrs =  ( 1 << MOSI_BB );
        else
            REG( PORT, SPI_BB_MOSI )->ovrc =  ( 1 << MOSI_BB );

        c <<= 1;

        /* half a clock cycle before leading/rising edge */
        DELAY_1US();

        REG( PORT, SPI_BB_SCK )->ovrs = ( 1 << SCK_BB );

        /* half a clock cycle before trailing/falling edge */
        DELAY_1US();

        /* read MISO on trailing edge */
        c |= ((REG( PORT, SPI_BB_MISO )->pvr >> MISO_BB) & 0x01);
        REG( PORT, SPI_BB_SCK )->ovrc = ( 1 << SCK_BB );
    }

    // Leave MOSI pin in inactive state
    REG( PORT, SPI_BB_MOSI )->ovrc =  ( 1 << MOSI_BB );

    DELAY_75US();

    return c;
}


/*============================================================================
Name    :   BitBangSPI_Send_Message
------------------------------------------------------------------------------
Purpose :   Send and Read one frame using BitBangSPI Interface
Input   :   n/a
Output  :   n/a
Notes   :	Called from Send_Message in QDebugTransport.c
============================================================================*/
void BitBangSPI_Send_Message(void)
{
    unsigned int i;
    uint8_t FrameInProgress;

    // Clear slave select to indicate start of frame
    REG( PORT, SPI_BB_SS )->ovrc =  ( 1 << SS_BB );
    
    // Send our message upstream
    for (i=0; i <= TX_index; i++)
    {
        FrameInProgress = RxHandler(BitBangSPI_Send_Byte(TX_Buffer[i]));
    }

    // Do we need to receive even more bytes?
    while (FrameInProgress)
        FrameInProgress = RxHandler(BitBangSPI_Send_Byte(0));

    // Set slave select to indicate end of frame
    REG( PORT, SPI_BB_SS )->ovrs =  ( 1 << SS_BB );
}
#endif 

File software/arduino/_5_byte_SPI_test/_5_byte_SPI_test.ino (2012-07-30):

/******************************************************************************/
/**
* \file test.ino
* \mainpage
* \section intro Introduction
* Arduino sketch to implemnent SPI MASTER side of loop-back communication.
*
* \section contactInfo Contact Information
* For more information and the latest release, please visit this projects home
* page at http://codinghead.github.com/touchshield/
* To participate in the project or for other enquiries, please contact Stuart
* Cording at codinghead@gmail.com
*
* \section license Licensing Information
* Copyright (c) 2012 Stuart Cording
*
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
* \author Stuart Cording aka CODINGHEAD
*
********************************************************************************/

// Sends 5 x 8-bit data via SPI to UC3C, incrementing by one after
// each transfer. Expects to receive sent data - 1 back from 
// UC3C. After 5 bytes, SS is raised again.
// UC3C code operates as a simple loop-back function
// Written for Arduino MEGA
// Arduino output sent and received data via Serial.print()
// LED (pin 13) blinks if received data is incorrect. Stays off
// permanently if it is correct.

// include the SPI library:
#include <SPI.h>

// Use Pin 13 to control LED
int led = 13;

// Variable for data to send to UC3C
byte dataSent = 0x00;
byte dataRead = 0x00;

// Use Pin 53 as SPI Slave Select
int slaveSelect = 53;

void setup() {
  /* Use Pin 13 as an output (LED) */
  pinMode(led, OUTPUT);
  /* Use Pin53 as SS slave select */
  pinMode(slaveSelect, OUTPUT);
  /* Enable serial output for debugging */
  Serial.begin(115200);
  /* Enable the SPI library */
  SPI.begin();
  /* Set SPI for MSB first, SPI Mode 0 and clock div 2 */
  SPI.setBitOrder(MSBFIRST);
  SPI.setDataMode(SPI_MODE0);
  SPI.setClockDivider(SPI_CLOCK_DIV2);
}

void loop() {
  // Set slave select signal low
  digitalWrite(slaveSelect,LOW);

  // Send five bytes of data in one transfer
  while(dataSent < 5)
  {
    dataRead = SPI.transfer(dataSent);
    
    // If data read was same as previous sent byte, turn LED off
    dataRead += 1;
    if (dataRead == 5)
    {
      dataRead = 0; 
    }
    if (dataSent == dataRead)
    {
      digitalWrite(led, LOW);
    }
    // Otherwise turn LED on to signal error output to Serial interface
    else
    {
      digitalWrite(led, HIGH);
      Serial.print(dataSent, HEX);
      Serial.print(" ");
      Serial.print(dataRead, HEX);
      Serial.println(" ");
    }
    // Increment value to be sent
    ++dataSent;
  }
  // End this transfer by setting SS high again
  digitalWrite(slaveSelect,HIGH);
  // Reset data to be sent back to 0
  dataSent = 0;
}

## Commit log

2012-07-01 Added EagleCAD schematic and board design.
    Schematic and board design (not yet complete) added to repo.
    [QTouchShield.brd, QTouchShield.sch]
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2012-07-02 Changed LQFP-144 footprint.
    Ripped up LQFP-144 package footprint and replaced by footprint from an
    offical EagleCAD library.
    [QTouchShield.brd, QTouchShield.sch]
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2012-07-02 Rotated AT32UC3C packge to correct position.
    Package was at wrong angle related to the related components. Fixed.
    [QTouchShield.brd]
2012-07-09 Added Creative Commons logo to schematic
    Imported Creative Commons Share Alike logo into the schematic.
    [QTouchShield.sch]
2012-07-11 Move hardware to 4-layer board.
    32-Touch channels in a reasonable board space was not working out. Moved
    to 4-layer board.
    [QTouchShield.brd]
2012-07-11 Added pin assignment table to project.
    Pin assignment table added. Links ARV32 pins to Arduino MEGA board layout
    plus defines other board signalling.
    [TouchShield-Pin-Assignment.xlsx]
2012-07-12 Further routing added on SNS and SNSK lines.
    [QTouchShield.brd]
2012-07-12 Added cuttable bridges for RESET and SPI.
    Added cuttable PCB bridges that allow default:
    - RESET switch of shield connected to RESET of Arduino
    - SPI interface selected as default interface
    Defaults can be changed by cutting the bridges through with a scalpel.
    [QTouchShield.brd, QTouchShield.sch]
2012-07-12 Added license text to schematic.
    [QTouchShield.sch]
2012-07-12 Added project logo to schematic.
    [QTouchShield.sch]
2012-07-12 Touched design - no major changes
    [QTouchShield.brd]
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2012-07-12 Added SketchUp and EagleUp files.
    [QTouchShield.skp]
2012-07-13 Updated Google SketchUp image with latest 3D models /*******************************************************************************
    [QTouchShield.skp]
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2012-07-13 Saved SketchUp with latest component additions.
    [QTouchShield.skp]
2012-07-27 Fixed error with the SPI MOSI/MISO connections.
    The MOSI/MISO connections were the wrong way round.
    Added the relationship between the UC3C MCU and the "Port Pins" on the
    STK600.
    [TouchShield-Pin-Assignment.xlsx]
2012-07-27 Added first test code for Arduino MEGA running SPI interface.
    Small sketch to output some data on the SPI interface as MASTER.
    Blinks LED on Pin13 after every transfer. Used to confirm that
    UC3C is working correctly as slave.
    [test.ino]
2012-07-27 Swapped MISO/MOSI connection to Arduino - wrong way round.
    The MISO/MOSI lines from the UC3C to the Arduino were swapped.
    Fixed in the schematic and board.
    [QTouchShield.brd, QTouchShield.sch]
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2012-07-27 Started progress report to help track open issues.
    Progress report helps to track open issues and make notes on any
    info noticed during development.
    [ProjectProgress.xlsx]
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2012-07-27 Added last missing file from UC3C SPI loop-back project.
    [conf_board.h]
2012-07-30 Added project progress tracker.
    Created basic tracker to kep note of progress and plan next steps.
    [ProjectProgress.xlsx]
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2012-07-30 Added initialisation of the oscillator and clock tree for UC3C.
    Initialised the clock to use internal 120MHz clock. This helps to ensure
    that the SPI in slave mode can handle the master's data transfer rates.
    [init.c]
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2012-07-30 Updated Arduino 5-byte SPI transfer test for maximum transfer speed.
    Test updated to run at ATmega's maximum SPI data speed and no waits
    during the transfer or post/prior to changing the SS slave select line.
    LED is now only turned on if data transfer fails. Otherwise it remains
    off.
    [_5_byte_SPI_test.ino]
2012-07-30 Update to progress tracker - re: SPI MASTER/SLAVE progress.
    [ProjectProgress.xlsx]
2012-07-30 Screen shots from logic-analyser taken during SPI testing
    Various screen shots taken during testing of SPI transfers.
    [full-speed-5-byte-transfer.csv]
2012-07-30 Finalised version of project with functional SPI slave.
    Finalised version of test code for SPI slave with correct settings for
    internal clocks etc.
    Will be used as basis for other tests prior to full application
    development.
    [init.c]
2012-07-30 Added firmware flow diagram to spreadsheet.
    Started rough firmware flow diagram for the code. Added it here to
    be with the pin assignments etc.
    [TouchShield-Pin-Assignment.xlsx]
2012-07-30 Modified naming of detect pins as being "per sensor".
    In keeping with the whole QTouch library, the detect pins are now
    named as being "per sensor", since a slider or rotor takes up 3
    channels which make up 1 sensor.
    [TouchShield-Pin-Assignment.xlsx]
2012-07-30 Updated progress tracking spreadsheet.
    [ProjectProgress.xlsx]
2012-07-30 Added comment regarding detect pins on schematic.
    Noted that detect pins output "channel" detections, not "sensor"
    detections, as defined in the QTouch library.
    [QTouchShield.sch]
2012-07-31 Added pin definition for QT600 interface board debug interface.
    Added SPI bit bang Data Interface pins for interfacing with the
    QT600 Interface Board to use with QTouch Studio for debugging.
    [TouchShield-Pin-Assignment.xlsx]
2012-07-31 Added TOUCH DATA header for data transfer to QT600 Interface Board
    TOUCH DATA header added. This is the bit-banged SPI interface for
    transferring debug data to the QT600 board for analysing touch data
    with QTouch Studio.
    [QTouchShield.brd, QTouchShield.sch]
2012-07-31 Starting adding decoupling capacitors in correct places.
    Decoupling caps being placed near to their associated pins. Not yet
    complete.
    [QTouchShield.brd]
2012-08-01 Completed routing of cap sense lines plus JTAG & QT600 Debug IF
    [QTouchShield.brd]
2012-08-01 Further board updates and pin changes.
    [QTouchShield.brd, TouchShield-Pin-Assignment.xlsx]
2012-08-02 Added drawings for pin headers and receptacles.
    Added 0.1" pitch SMD header drawings needed for PCB footprints.
    [component-info.xlsx]
2012-08-02 Added new Leaded Component version of QTouch Shield.
    Added new version of shield that allows leaded caps and resistors to be
    fitted between the AVR32 and the capacitive sensors.
    First version of the new board.
    [QTouchShield.brd, QTouchShield.sch]
2012-08-03 Added USB Connector (B-Large) for firmware updates.
    [QTouchShield.sch]
2012-08-03 Board ripped up - new surface mount headers fitted.
    Ripped-up entire board. Most headers have been changed to surface mount
    type.
    [QTouchShield.brd]
2012-08-03 Added new surface mount header datasheet and SketchUp Model.
    [M20.skp]
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2012-08-03 Added new HARWIN connector to list
    [component-info.xlsx]
2012-08-03 Added TODO list to Excel file.
    [ProjectProgress.xlsx]
2012-08-03 Major update to LC version of shield.
    Major update to shield design including:
    - Moving headers to surface mount technology
    - Including level shifters for SPI and USART i/f
    - USB connector for firmware flash upgrade (not yet complete)
    - Jumper system for selecting MEGA or UNO style SPI interface
    - Plus other tidying up
    [QTouchShield.brd, QTouchShield.sch]
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2012-08-09 Another attempt, more successful, at routingh the board!
    [QTouchShield.brd, QTouchShield.sch]
2012-08-09 Updated the Pin Assignment file.
    [TouchShield-Pin-Assignment.xlsx]
2012-08-09 Added full list of STK600 pins to AVR32 MCU pinning list.
    [TouchShield-Pin-Assignment.xlsx]
2012-08-09 95% complete routing of board; extra VCC decoupling; USB changes.
    Routing about 95% complete.
    Added extra 10uF cap in the VCC supply.
    Added in-line resistors in the D+/D- lines.
    [QTouchShield.brd, QTouchShield.sch]
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2012-08-09 Split Arduino reset electrically from UC3 & JTAG reset signals.
    Split resets. If user wants to reset Arduino from switch, they have to
    solder blob the jumper by hand.
    [QTouchShield.brd, QTouchShield.sch]
2012-08-10 Final routed board for LC version.
    Board finally routed with the LC layout.
    No known major issues to resolve.
    Consider only ground-plane under MCU and review from STROHAL.
    [QTouchShield.brd, QTouchShield.sch]
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2012-08-21 Updated pin assignment documentation related to testing undertaken.
    [TouchShield-Pin-Assignment.xlsx]

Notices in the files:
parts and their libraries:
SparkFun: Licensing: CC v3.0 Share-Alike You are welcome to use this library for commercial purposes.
